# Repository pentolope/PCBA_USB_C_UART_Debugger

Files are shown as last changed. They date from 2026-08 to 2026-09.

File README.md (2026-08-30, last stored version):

# USB-C UART Debug Adapter

USB-C to 3.3 V UART debug adapter: bus-powered USB 2.0 Full-Speed device breaking out TX/RX/GND/3V3 and optional RTS/CTS.

This repository holds the design problem for a **USB-C to 3.3 V UART debug adapter**. The brief fixes the function and the interface contract: a bus-powered USB 2.0 Full-Speed device with a correct USB-C device-side CC network, USB ESD protection close to the connector, local decoupling, and a target-side header carrying TX, RX, GND, a 3V3 reference and optional RTS/CTS on a 0.1-inch or compact locking header. It also fixes process intent: pick a commonly available USB-UART bridge, prefer two layers, route D+/D- as a deliberate differential pair, and document whatever impedance approximation is used. The brief's own modality is carried across unchanged: RTS/CTS is offered as an option, two layers is a preference, and the benchmark-intent clauses say what the repository *should* do rather than what it must.

Everything else is the design agent's to decide. The brief names no bridge IC, no connector part, no ESD device, no board outline, no stackup numbers and no impedance target — those belong in `open_decisions`, not in this README. Where a choice is made during design it must be made and justified against cited evidence, not back-filled into the brief as if the user had asked for it.

> **This board has not been designed.** There is no schematic, no layout and no
> part selection here — only the brief, a reading of the brief, and the
> scaffolding a design run needs. That is the intended state of this repository,
> not a gap in it.

## What the brief fixes, and what it leaves open

The brief pins down 16 requirements and deliberately leaves
17 decisions to whoever designs the board. The `Source` column says
which is which: `brief` is quoted from [BRIEF.md](BRIEF.md), `metadata` comes
from the benchmark catalogue, and `open` means the brief does not fix it.

| Aspect | Value | Source |
|---|---|---|
| Product function | USB-C to 3.3 V UART debug adapter | brief |
| UART signalling level | 3.3 V | brief |
| USB interface class | USB 2.0 Full-Speed device | brief |
| Power source | Bus-powered (no separate supply input stated) | brief |
| Target-side signal set | TX, RX, GND, 3V3 reference, plus RTS/CTS as an option | brief |
| Target-side header style | 0.1-inch header or a compact locking header (the brief permits either; which one is not fixed) | brief |
| USB-C CC network | Correct device-side CC network required; no topology, value or tolerance stated | brief |
| ESD protection | USB ESD protection, placed close to the connector | brief |
| Decoupling | Local decoupling required | brief |
| Connector placement | USB and target-side connectors clearly separated | brief |
| USB-UART bridge | A commonly available bridge; no specific part named by the brief | brief |
| D+/D- routing | Deliberate differential pair; any impedance approximation must be documented | brief |
| Likely layer count | 2 (stated as a preference, not a mandate) | metadata |
| Primary stressors | USB 2.0 differential routing, ESD, USB-C CC resistors, small QFN | metadata |
| Board outline, size and mounting | Not fixed by the brief — design agent's choice | open |

The full split, with the verbatim brief text substantiating every fixed
requirement, is in [board/requirements.md](board/requirements.md) and
machine-readably in [board/requirements.json](board/requirements.json).

**Missing details are design freedom, not permission to fabricate unstated user
requirements.** A choice the brief left open is recorded as a decision, with its
reasoning — never promoted into a requirement.

## Benchmark position

| | |
|---|---|
| Benchmark id | 5 of 32 |
| Category | high-speed-lite |
| Difficulty | 2 / 5 |
| Brief detail | 3 / 5 |
| Likely layer count | 2 |
| Primary stressors | USB 2.0 differential routing, ESD, USB-C CC resistors, small QFN |

Board 05 sits in the `high-speed-lite` category at difficulty 2/5 with brief detail 3/5: an adapter of modest scope whose difficulty concentrates in doing four specific things correctly at once — USB 2.0 differential routing, ESD, the USB-C CC resistors, and a small QFN. The brief is deliberately mid-detail: it pins down the interface contract (speed class, power source, signal set, header style, protection placement) while naming no part, no dimension and no impedance number. The interesting test is the "Prefer two layers, but route D+/D- as a deliberate differential pair and document any impedance approximation" clause — it invites a controlled-impedance claim on a stackup that may not be able to guarantee one, and rewards an agent that documents the approximation honestly rather than asserting a number.

This repository is one of thirty-two. The suite, the protocol and the results
live in [PCBA_AutoDesignAndTest_Bench](https://github.com/pentolope/PCBA_AutoDesignAndTest_Bench).

## Repository layout

| Path | Contents |
|---|---|
| `BRIEF.md` | the supplied brief — authoritative, preserved byte for byte, never edited |
| `board/requirements.md` | what the brief fixes, what it leaves open, and where decisions get recorded |
| `board/requirements.json` | the same split, machine-readable, each fixed requirement bound to brief text |
| `board/manifest.template.json` | the toolkit's minimum manifest, pre-filled for this board |
| `board/toolchain.json` | where this board's build finds KiCad and the router |
| `benchmark/metadata.json` | the supplied catalogue entry — category, difficulty, detail, stressors |
| `docs/architecture.md` | the decisions this board must make, as questions, unanswered |
| `docs/sources.md` | the classes of evidence the design will have to cite |
| `docs/status.md` | what exists, what does not, and what is deliberately absent |
| `candidates/` | disposable search output, ignored by Git |
| `.claude/skills/` | the accountability-review skill [CLAUDE.md](CLAUDE.md) requires before a push |
| `tooling/PCBA_AutoDesignAndTest` | the shared verification/routing/release toolkit, as a pinned submodule |

## Getting the repository

The toolkit is a submodule and carries KiCad Routing Tools as a submodule of its
own, so clone recursively:

```bash
git clone --recursive https://github.com/pentolope/PCBA_USB_C_UART_Debugger.git
```

```bash
git submodule update --init --recursive
```

## Designing the board

Generic verification, routing and release logic is **not** written here. It is
consumed from `tooling/PCBA_AutoDesignAndTest`, which is board-agnostic by
construction and must stay that way; this repository owns the board and nothing
else. Start from
[the toolkit's onboarding guide](tooling/PCBA_AutoDesignAndTest/examples/onboarding.md),
and see [CLAUDE.md](CLAUDE.md) for the rules a design run works under.

```bash
python3 tooling/PCBA_AutoDesignAndTest/run.py preflight
```

## Brief integrity

`BRIEF.md` SHA-256 `0c5897542317b8fdc90d1251febe01efa33c86589f59024910c426d053b9a461`

Every quotation in `board/requirements.json` is bound to those exact bytes. If
the brief ever changes, the bindings are stale by construction — which is the
point of recording the digest.

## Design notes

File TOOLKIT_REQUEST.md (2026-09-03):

# Toolkit request from board 05 (USB-C UART debugger)

This is a request list from one board to the toolkit it is validated by. It
was written after taking this board from a brief to a release-ready commit,
and every item below is a wall this board actually hit, quoted where the
toolkit says in its own words what it will not do.

Two rules govern the list:

1. **Nothing here may make the toolkit board-specific.** Each request states
   the general form the facility should take. Where this board is mentioned
   it is as the reporter of a wall, never as the shape of the answer. A
   request that could only be satisfied by knowing about USB, Type-C, or any
   part on this board has been rewritten until it no longer is.
2. **Nothing here asks the toolkit to be less strict.** Every facility
   requested must fail closed, refuse rather than guess, carry its model and
   its validity window in the claim, and be reachable only by an explicit
   manifest declaration. Several of these requests exist *because* the
   toolkit correctly refused, and the fix is a new model, not a relaxed one.

Priority is the order in which these would change what a board can honestly
claim, highest first.

| # | Request | Doc | Blocks today |
|---|---|-----|---|
| 1 | Coupled-line model for differential pairs | §21.2 | An UNKNOWN impedance claim on any pair-carrying board |
| 2 | Reactive interconnect models for post-layout simulation | §21.1, §22 | Half of §22's own question list |
| 3 | Plane and multi-path DC, and PDN quantities | §23 | Any rail with decoupling; every poured net |
| 4 | Verification-method classification | §26 | Not expressible in the claim model |
| 5 | External and manual release dependencies | §25, §30 | Nowhere to record what is verified off-tool |
| 6 | Fabricator facts the catalog does not carry | §7, §25 | Two via gates permanently NOT_APPLICABLE |
| 7 | Component rotation as a toolkit facility | §25 | Per-board duplication; unreviewed CPL angles |
| 8 | Correlated uncertainty in matched groups | §21.1 | Undecidable skew on unavoidable geometry |
| 9 | A defined seam for full-wave extraction | §21.3 | No path from geometry to a solver |

---

## 1. A coupled-line model for differential pairs

### What stopped me

The toolkit refuses, correctly and in full:

```
REFUSED: differential solving is not implemented in this pass: the analytic
infrastructure carries no coupled-line model, and an uncoupled pair presented
as a differential answer would be wrong by construction
```

`pcbqa/transmission_line.py` implements bare microstrip, coated microstrip
and stripline, all single-ended. `run.py fab impedance` already accepts
`--mode differential`, so the interface exists and the model behind it does
not.

The consequence for this board is one claim that cannot be resolved:
`usb_pair_differential_impedance_matches_the_usb_nominal` reports UNKNOWN,
with the omission recorded as *"no coupled-line model is available"*. That is
the honest answer, and it is the only unresolved electrical question on an
otherwise fully evaluated board. Any board carrying a differential interface
will land in the same place.

Two supporting facts, both already inside the toolkit:

- `pcbqa/coupling_geometry.py` measures coupled run length and says of its
  own output: *"geometric proximity for risk ranking only; this is coupled
  run length in mm, not a crosstalk voltage, and no electrical conclusion
  follows until a sourced coupling model consumes it."* Nothing consumes it,
  and no gate reaches it, so a board cannot even obtain the inventory.
- `pcbqa/claim.py` already reserves the phenomena `characteristic_impedance`
  and `coupling` and the scope level `pair`. The vocabulary was designed for
  this; only the producer is missing.

### What I want

A coupled two-conductor model beside the existing single-ended ones, with the
same discipline: a stated form, a stated validity window on the normalised
geometry, and a refusal outside it rather than an extrapolation.

- odd- and even-mode impedance, and differential and common-mode impedance
  derived from them;
- edge-coupled microstrip (bare and mask-coated) and edge-coupled stripline,
  since those are the geometries a two-conductor pair on a fabricated board
  actually takes;
- the same effective-permittivity helpers the delay model uses, so impedance
  and delay can never disagree about the geometry — the single-ended code
  already makes that promise and the coupled code should inherit it;
- consumption of the existing coupled-run-length inventory, so the model is
  applied to the length the board really runs coupled and not to a declared
  ideal.

Second, a **fabricator-report path** for boards that can buy impedance
control. The frozen catalog already carries the fabricator's impedance model
inputs — prepreg and core Dk by thickness, soldermask Dk, the offered
differential range, and `Impedance Tolerance ±10%`. It also records that
controlled impedance is offered only at `4/6/8/10/12/14/16/18/20/.../32
layers`. That last fact is a first-class answer the toolkit should be able to
give: on a two-layer construction no fabricator impedance report can exist,
so a model is the only route to the claim, and a board should learn that from
the toolkit rather than deduce it.

### Interface

- `pcbqa.transmission_line.coupled_microstrip_zdiff(...)` and the stripline
  equivalent, returning odd/even mode plus effective permittivity, refusing
  outside the window.
- `run.py fab impedance --mode differential` stops refusing where the
  construction and geometry are inside the model's window; keeps refusing,
  with the reason, where they are not.
- A gate, opt-in like every other: `SI.PAIR_IMPEDANCE`, driven by a
  `differential` block under an existing `timing.interfaces.<name>` —
  conductor width, edge-to-edge gap, reference layers, target impedance and
  tolerance. It measures the realised geometry off the board, not the
  declared geometry, exactly as the delay gate does.

### How it must refuse

- Outside the validity window of the form: refuse, naming the geometry ratio
  and the window.
- Where the two conductors are not uniformly coupled over the measured run
  (fan-out, launch, via transitions): report the uncoupled portion as an
  explicit omission, in the same shape the delay gate uses for unreferenced
  length, and let the board declare a budget for it.
- Where the reference structure under the pair is interrupted beyond that
  budget: refuse, because an impedance stated over a broken reference
  describes a structure the board does not have.

### Done when

A board can declare a differential interface and receive PASS, FAIL or a
stated refusal — never silence — and the claim carries the model name, the
validity window, and the coupled length it was evaluated over.

---

## 2. Reactive interconnect models for post-layout simulation

### What stopped me

The extracted interconnect model is a resistor. Literally:

```python
"spice": ".subckt {identity} a b\nR1 a b {value}\n.ends"
```

and the geometry baseline says of itself: *"geometry-derived quantities only;
no inductance or capacitance is claimed anywhere in this report."*

§22 lists the questions post-layout simulation exists to answer. With an
R-only model, these are unanswerable on any board: *did via inductance create
ringing?*, *did the decoupling-loop geometry degrade transient behaviour?*,
*did a switching loop become too inductive?*, *did the routed impedance
invalidate the nominal termination?* The rail-drop questions are answerable
and the reactive ones are not, which quietly limits post-layout simulation to
DC.

### What I want

Per-unit-length capacitance and inductance from the same geometry and
stackup the propagation model already uses, and via barrel inductance beside
the via *delay* model that already exists, emitted as a richer subcircuit
under the same alias mechanism that makes extracted models usable from a
stored scenario.

- a distributed or lumped-segment RLC subckt, segment count chosen from the
  path's own electrical length so the model is not finer or coarser than the
  question deserves;
- the R-only model kept and still selectable, because for a pure DC drop it
  is the honest minimum and costs nothing;
- the choice declared by the board, not inferred: a scenario asks for the
  model it wants and the toolkit refuses if it cannot build it.

### How it must refuse

The reactive model must inherit the delay model's reference discipline: if a
portion of the path runs with its reference interrupted beyond the board's
declared budget, refuse rather than emit an inductance computed from a loop
that is not there. This is the same rule that already governs delay, and it
is the reason the delay numbers on this board can be trusted.

### Done when

A board can substitute a routed path into a pre-layout scenario and see a
transient that differs from the ideal one for reasons the model can name.

---

## 3. Plane and multi-path DC, and the power-integrity quantities

### What stopped me

`extract.path_resistance` refuses two situations that are not exceptional —
they are what supply distribution normally looks like:

```
net 'GND' carries filled zone copper; plane current paths are not modelled by
path-scoped DC extraction
```

```
traversal element 32 on net '+3V3' begins and ends in one electrical node;
its series resistance would be fictitious, and the path-scoped model refuses
```

Both refusals are right. Their combined effect on this board is that the
regulator output rail — the one with the decoupling on it — cannot be
measured at all, and neither can any return path, because the return is a
pour. What can be measured is only what happens to be a bridge in the graph.
On this board that left the receptacle-to-regulator run (36.3 mΩ over
21.4 mm, two vias), the switched supply to the target header (24.5 mΩ), and
the series-terminated signal runs. The decoupled rail and the ground return
are invisible.

§23 asks for source-to-load DC resistance, distribution voltage drop,
via/current bottlenecks, plane spreading resistance, decoupling-loop
inductance, plane inductance, local supply impedance, PDN impedance versus
frequency, anti-resonances and transient droop. Today a board can obtain the
first of those only when the copper happens to be a single series chain.

### What I want

1. **A network DC solve.** Where parallel copper exists, return the network
   resistance between the named terminals instead of refusing. Parallel
   copper divides current, which is a solvable fact, not an ambiguity. Keep
   the refusal for the case it was written for — a *series* model asserted
   over a parallel network — by making the network solve a different,
   explicitly requested answer with its own claim shape.
2. **Poured nets included.** A nodal solve over the filled zone polygons,
   with the vias as the connections between layers, giving source-to-load
   resistance including plane spreading. This is the only route to a return
   path number on any board that uses a plane, which is nearly all of them.
3. **Decoupling-loop inductance from geometry.** The claim vocabulary already
   reserves `loop_inductance` and nothing produces it. The loop is
   measurable: pad, via, plane, via, pad, all present in the board file.
4. **Current bottlenecks.** Given a rail and a current, report the narrowest
   cross-section and the via count carrying it, which is a geometry question
   the toolkit can already answer and nobody can currently ask.

### Interface

A `power` block in the manifest, opt-in, listing rails: a source terminal,
load terminals, the current each draws, and the drop each tolerates. Gates
`PDN.DC_DROP` and `PDN.RETURN_PATH`, reporting measured drop against the
declared limit, and the return path's resistance against its own.

### How it must refuse

State the solver, the mesh resolution and the convergence criterion in the
claim. Refuse when the pour is unfilled, when a zone's fill is stale with
respect to the copper, or when a declared terminal is not on the net.

---

## 4. Verification-method classification

### What stopped me

§26 asks that every significant requirement identify the strongest
verification method currently available, from a stated vocabulary. No claim
in this board — or in any board in this bench — carries one. The nearest
thing is `evidence_class`, which is free text and describes the evidence
rather than the method that established it.

The gap matters most where a requirement is *satisfied by argument*. This
board's ESD claims establish that every entering conductor is clamped, which
is a structural fact, not a compliance result. Nothing in the artifact says
that the compliance claim itself requires physical test. §26 explicitly wants
that distinction, and there is nowhere to write it.

### What I want

A closed vocabulary as a first-class claim field — `STATIC`, `GEOMETRY`,
`ANALYTIC`, `CIRCUIT_SIM`, `DIGITAL_SIM`, `EXTRACTED`, `EM_SIM`,
`THERMAL_SIM`, `MANUFACTURING_CHECK`, `PHYSICAL_TEST`, `DOCUMENTATION` — with
a claim able to name more than one, and able to name a method it does *not*
have as the one that would be required to close it.

A gate, `PROV.VERIFICATION_METHOD`, that checks every requirement-bearing
claim names a method, and lets a board declare a minimum method per
significance class, so a board can say that its safety-relevant requirements
may not rest on `DOCUMENTATION` alone.

### How it stays board-agnostic

The vocabulary is fixed by the toolkit; which method a claim carries is the
producer's statement; which minimum a board demands is the board's policy.
Nothing about any particular requirement is encoded in the toolkit.

---

## 5. External and manual release dependencies

### What stopped me

§25 says of steps that cannot be validated locally that they *"should be
recorded as external/manual release dependencies rather than silently
assumed"*, and §26 says the agent should be rewarded for correctly saying
physical validation is still required.

There is nowhere to record either. `release-check` prints RELEASE READY or a
list of failures; a board with an open dependency on a fabricator's assembly
preview, a physical ESD test, or a bench measurement of a quantity no model
can establish has no way to carry that in the artifact. The absence reads as
"nothing is outstanding", which is exactly the silent assumption the document
warns against.

### What I want

An `external_dependencies` block in the manifest, and a gate over it. Each
entry: an id, the statement it would establish, the verification method from
§26's vocabulary, who owns it, its status, the evidence that closes it, and
whether it blocks release. The gate checks the shape and the evidence;
`release-check` prints open dependencies as part of its verdict and refuses
release-ready while a blocking one is open.

Alongside it, §30's policy states — `analysis-only`,
`provisional-layout-allowed`, `fabrication-ready`, `release-ready`,
`requires-human-review`, `blocked` — as an explicit output of validation
rather than something a reader infers from a gate table. A positive result at
one stage should not read as authorisation for the next, and today it does.

---

## 6. Fabricator facts the catalog does not carry

### What stopped me

`fab/selection.json` states its own limits precisely: *"feasible means
feasible against the checked requirements only; the properties under
not_in_vocabulary were NOT inspected and must be judged separately"*, and the
uninspected list includes solder-mask constraints, via covering (tented /
plugged / filled), annular ring, edge-to-copper clearance and assembly
constraints.

The frozen catalog carries soldermask *thickness* — base, on copper, between
traces — but no mask expansion, registration or minimum dam. So
`via_mask.process.limit_mm` cannot be sourced from evidence, and
`VIA.MASK_CLEARANCE_PROCESS` and `VIA.NATIVE_GERBER_AGREEMENT` are
NOT_APPLICABLE on every board in this bench. The gates exist and nothing can
legitimately turn them on.

### What I want

Extend the catalog vocabulary to the properties in that list, under the same
committed-evidence policy the rest of it follows: source, retrieval date,
excerpt, digest. Then expose them, so a board writes

    "via_mask": {"process": {"limit_mm": {"from_catalog": "soldermask_min_dam_mm"}}}

instead of inventing a number or leaving the gate dark. The same applies to
via covering: a board should be able to declare tented, plugged or open and
have the declaration checked against what the fabricator offers, because that
choice changes what the via gates mean.

---

## 7. Component rotation as a toolkit facility

### What stopped me

Rotation correctness is a per-part fact about a fabricator's library, not
about a board, and it is currently implemented per board: an earlier board in
this bench carries its own `tools/jlc_orientation.py` plus per-part frozen
library responses, and derives each offset by pairing library pads against
footprint pads. This board has neither, so its CPL ships KiCad's angles with
nothing behind them — and a wrong rotation on a fine-pitch package is a
scrapped build, not a warning.

Copying a tool between boards is exactly the duplication a board-agnostic
toolkit should absorb. The gate for it, `CPL.ORIENTATION`, is already in the
toolkit; only the means of producing evidence for it is not.

### What I want

A `fab orientation` subcommand: fetch a part's library geometry under the
same network policy that governs `fab refresh` — that is, never during
validation — derive the offset by pad pairing, require every pad to agree,
score the runner-up, and write per-part evidence with a digest. A board then
declares the registry and reviews it; the gate re-derives from the committed
evidence and compares.

The pad-pairing derivation is general: it needs a footprint and a library
geometry, and knows nothing about the part.

---

## 8. Correlated uncertainty in matched groups

### What stopped me

The skew gate treats each member's length uncertainty as independent. Before
I redrew this board's pair, all four of its paths carried exactly 0.9625 mm
of junction ambiguity — identical, because the endpoints are identical — and
the group spread came out as the interval 0 to 1.925 mm against a 0.2 mm
limit. Not a failure: undecidable, by construction, for any matched pair
whose members share their endpoint geometry.

I closed it in the board by ensuring nothing lands part-way along a
conductor, which removed the ambiguity rather than cancelling it. That fix is
not always available: a board whose group members must pass through a pad or
a via mid-run has no route to a decidable skew number, however well matched
the copper is.

### What I want

Either a way for a group to declare that its members' endpoint ambiguity is
shared — checked, not asserted, by comparing the junction identities the
extraction already computes — or a spread calculation that cancels the
ambiguity it can prove is common and reports only the residual. The gate
should still report the ambiguity it cancelled, so the reader can see what
was assumed.

---

## 9. A defined seam for full-wave extraction

§21.3 is right that the hard part is not calling a solver: it is geometry
translation, meshing, ports, references, boundaries and de-embedding. I am
not asking the toolkit to own a solver. I am asking for the seam to be
defined now, so the boundary is a decision rather than an accident.

A documented region export — an electrical path, the copper around it within
a stated distance, the stackup, and port definitions at named terminals —
written in a form a solver can consume and a claim can cite. Whatever
consumes it must refuse release-grade claims when port definition, reference
definition or de-embedding cannot be established, which is what the document
already asks for.

The candidates on a board like this one are the connector launch and the via
transitions — precisely the places the analytic model already declares
outside its validity.

---

## What I am not asking for

- Anything that names a bus, a connector family, a part or a vendor part
  number in toolkit code.
- Any relaxation of a refusal. Where the toolkit refuses today it is right to
  refuse; the request is a model that makes the refusal unnecessary, not a
  switch that suppresses it.
- Any gate that passes by default. Everything above is opt-in by manifest
  declaration and NOT_APPLICABLE until a board declares it, like every gate
  that exists now.
- Any facility that reads the network during validation.

## What this board would do with each

1. Close its differential-impedance claim, or receive a stated refusal that
   names the geometry rather than the missing model.
2. Rerun its hot-plug and edge scenarios over routed copper with reactive
   parasitics, not just resistance.
3. Measure the drop to its regulator across the decoupled rail, and the
   return path through the pour, neither of which it can measure now.
4. Mark its ESD coverage as an argument requiring physical test, in the
   artifact rather than in prose.
5. Record the assembly-preview and physical-test dependencies it currently
   cannot state at all.
6. Turn on the two via gates that are dark for want of a sourced number.
7. Ship a CPL whose angles have been derived and reviewed rather than
   inherited.
8. Keep its skew claim decidable if the pair ever has to pass through
   something mid-run.
9. Point a solver at its receptacle launch when the analytic answer is not
   enough.

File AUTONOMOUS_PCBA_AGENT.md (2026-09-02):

# Autonomous PCBA Agent — Architecture and Development Plan

**Status:** Working architecture / roadmap  
**Scope:** Board-agnostic autonomous PCBA development using KiCad and the `PCBA_AutoDesignAndTest` toolkit  
**Manufacturing target:** JLCPCB unless the toolkit's scope is deliberately changed in the future  
**Primary goal:** Enable an AI agent to turn a product brief into a defensible, manufacturable PCBA with minimal human interaction, while keeping every machine-readable claim inside the evidence actually established.

---

# 1. Mission

The system is intended to develop real PCBAs, not merely produce plausible schematics or visually convincing layouts.

The long-term autonomous flow is:

```text
product brief
    ↓
requirements + assumptions
    ↓
architecture + component selection
    ↓
schematic
    ↓
static schematic verification
    ↓
pre-layout electrical / functional simulation
    ↓
fabrication process + stackup
    ↓
placement + routing constraints
    ↓
placement
    ↓
routing
    ↓
physical validation
    ↓
parasitic extraction
    ↓
post-layout electrical / functional simulation
    ↓
targeted SI / PI / EM / thermal analysis where required
    ↓
design iteration
    ↓
fabrication + assembly outputs
    ↓
release gates
```

The objective is not an AI that merely "draws a PCB." The objective is an autonomous electrical-design system that can:

- interpret an incomplete human brief;
- derive reasonable engineering requirements;
- make and record assumptions;
- select defensible components and architectures;
- build and verify a schematic;
- simulate what can be simulated before spending effort on PCB layout;
- express physical intent as machine-readable constraints;
- use search/optimization for placement and routing;
- extract geometry-dependent electrical behavior;
- repeat simulations with the physical interconnect included;
- diagnose failures in terms of design variables;
- revise the design until the available evidence supports the required claims;
- generate reproducible fabrication and assembly outputs;
- refuse claims that the available evidence does not support.

The system should optimize for **conservative autonomy**: proceed autonomously when a decision is reversible and sufficiently supported, but never convert missing evidence into an implicit PASS.

---

# 2. Implementation context and architectural boundaries

This document describes both current foundations and future target capabilities.

The existing `PCBA_AutoDesignAndTest` toolkit already provides important pieces of the architecture, including:

- KiCad-centered validation;
- fail-closed result handling;
- board-owned declarative policy;
- fabrication and release evidence;
- routing provenance and candidate isolation;
- electrical-path analysis;
- parasitic-related analysis;
- component delay/model concepts;
- simulation scenario, fidelity, digital, and ngspice infrastructure;
- JLCPCB process evidence;
- reproducible release checks.

Not every capability described in this roadmap exists yet.

A future backend or solver must not be represented as implemented merely because the architecture anticipates it. Production code should expose a capability only when there is a real implementation and a defined result contract.

The architecture therefore distinguishes:

```text
implemented capability
planned capability
unsupported capability
```

An unsupported capability is not a degraded PASS.

---

# 3. Roles and authority

The system should divide responsibilities deliberately.

## 3.1 AI agent

The AI is the electrical engineer and iteration controller.

It is responsible for:

- interpreting the product brief;
- deriving requirements;
- recording assumptions;
- selecting architectures;
- selecting components;
- locating and interpreting source evidence;
- choosing which simulations and analyses are necessary;
- defining electrical intent;
- defining placement and routing constraints;
- interpreting failures;
- deciding which design variables to modify;
- deciding when additional analysis is warranted;
- explaining unresolved uncertainty.

The AI should normally specify **intent and constraints**, not manually choose every trace vertex or component coordinate.

---

## 3.2 KiCad project

Native KiCad files are authoritative for the realized electrical and physical design.

They are the authority for things such as:

- schematic connectivity;
- assigned symbols and footprints;
- PCB geometry;
- copper;
- pads;
- vias;
- zones;
- board outline;
- stackup representation;
- net classes;
- design rules.

A generator may be the source of the intended design, as in a generated-board workflow, but the generated KiCad design still must be independently checked for parity with that source.

Nothing is considered physically true merely because a planning document or Python object says it is true.

---

## 3.3 PCBA_AutoDesignAndTest toolkit

The toolkit is the machine-facing authority for:

- validation;
- evidence provenance;
- constraint interpretation;
- model coverage and fidelity;
- physical measurements derived from authoritative design data;
- routing provenance;
- simulation result contracts;
- fail-closed behavior;
- manufacturing validation;
- fabrication artifact binding;
- release gates.

The toolkit should measure and judge declared policy. It should not silently invent board-specific policy.

Board-specific requirements belong in the board repository.

---

## 3.4 Optimization and geometry engines

Numerical/search engines should handle problems where explicit coordinate generation by a language model is weak or unnecessarily brittle.

Examples:

- component placement;
- placement legalization;
- ordinary routing;
- differential routing;
- length or time tuning;
- routing candidate generation;
- candidate ranking;
- geometric optimization.

The AI defines what a good solution means. Search engines explore the geometric solution space.

---

## 3.5 Simulation and extraction backends

Simulation backends establish modeled electrical or functional behavior.

Extraction backends establish physical quantities from PCB geometry.

They must report:

- what was analyzed;
- with what model;
- at what fidelity;
- under what conditions;
- with what omissions;
- with what provenance;
- whether the result is exact, bounded, approximate, unknown, or unsupported where applicable.

A simulator completing successfully does not by itself establish that its models were adequate for the claim being made.

---

## 3.6 Git

Git is the authority for design history and release identity.

Use Git for:

- immutable history;
- branches;
- comparison;
- rollback;
- submodule pins;
- release tags.

Do not invent a parallel revision-control state machine.

A substantial design alternative should be an isolated branch or reproducible candidate, not an undocumented mutation of the accepted board.

---

# 4. Engineering statement types

The autonomous agent should preserve the origin and status of important engineering statements.

At minimum, distinguish:

## 4.1 User requirement

A requirement explicitly stated by the product brief or human stakeholder.

Example:

```yaml
kind: user_requirement
statement: board shall operate from a 5 V host supply
source: product_brief
```

---

## 4.2 Derived engineering requirement

A requirement the agent derives because it is necessary to satisfy a user requirement, safety condition, interface contract, manufacturing constraint, or established engineering limit.

Example:

```yaml
kind: derived_requirement
statement: USB data traces require controlled differential routing
derived_from:
  - USB 2.0 interface requirement
rationale: interface electrical requirements
```

Derived requirements should state their rationale and evidence.

---

## 4.3 Assumption

A fact the brief did not establish but the design currently depends on.

Example:

```yaml
kind: assumption
statement: relay contacts will switch 24 VDC loads
reason: load voltage was not specified
revisable: true
```

Assumptions must remain visible because later evidence may invalidate them.

---

## 4.4 Design decision

A choice among multiple valid implementations.

Example:

```yaml
kind: design_decision
statement: use a star-point current-sense return
alternatives_considered:
  - shared return plane
  - dedicated sense return
rationale: reduce load-current error coupling
```

A design decision must not be presented as though it were a user requirement.

---

## 4.5 Verification requirement

A statement that defines what evidence is needed to establish another requirement.

Example:

```yaml
kind: verification_requirement
requirement: output rail transient droop
method:
  - pre_layout_spice
  - post_layout_spice_with_extracted_pdn
```

This separation makes failures diagnosable. A board can fail because the AI derived the wrong requirement, made a bad assumption, implemented a valid requirement incorrectly, or failed to verify it adequately.

---

# 5. Evidence and claim discipline

The architecture should converge on one conservative evidence vocabulary rather than creating independent notions of "quality" in every subsystem.

A produced quantity should carry, where relevant:

- phenomenon;
- scope;
- value and units;
- knowledge form:
  - exact value;
  - lower bound;
  - upper bound;
  - interval;
  - approximate;
  - unknown;
- evidence class;
- source/provenance;
- applicability;
- operating conditions;
- assumptions;
- omissions;
- requirement being evaluated;
- verdict.

Core rules:

1. **Unknown is not PASS.**
2. **An omitted contribution is not zero.**
3. **A reason for omitting a contribution is not a measurement.**
4. **A lower bound can prove that a maximum is exceeded, but cannot prove that the maximum is met.**
5. **A model that does not cover the required phenomenon cannot be upgraded by another strong model elsewhere in the simulation.**
6. **Simulator convergence is not model adequacy.**
7. **A nominal-design result is not automatically a fabrication or release result.**
8. **A report must not claim more than its dependency closure supports.**

Where the toolkit already has an evidence/claim representation, new producers should migrate into it rather than defining another parallel verdict system.

---

# 6. Repository architecture

## 6.1 PCBA repository

A board repository should own the physical hardware contract and board-level verification intent.

A representative target layout is:

```text
PCBA/
├── schematic/
├── pcb/
├── constraints/
│   ├── requirements.*
│   ├── assumptions.*
│   ├── electrical_paths.*
│   ├── placement.*
│   └── routing.*
├── components/
│   ├── selection.*
│   ├── pin_mappings.*
│   ├── models.*
│   └── provenance.*
├── interfaces/
│   ├── signals.*
│   ├── pins.*
│   ├── clocks.*
│   ├── protocols.*
│   └── electrical_limits.*
├── simulation/
│   ├── scenarios/
│   ├── spice/
│   ├── digital/
│   └── fixtures/
├── extracted/
│   ├── parasitics/
│   ├── sparameters/
│   └── power/
├── fabrication/
├── assembly/
├── generated/
├── docs/
└── tooling/
    └── PCBA_AutoDesignAndTest/
```

This is an architectural organization, not a requirement to rename an existing consumer repository.

The board repository should own:

- product and derived requirements;
- assumptions;
- architecture decisions;
- selected components;
- source provenance;
- schematic and PCB;
- physical/mechanical constraints;
- JLCPCB process and selected stackup;
- pin and electrical interface contracts;
- placement/routing intent;
- timing, impedance, power, safety, thermal, and signal-integrity requirements;
- board-level behavioral models;
- simulation scenarios;
- extracted PCB parasitics and S-parameters;
- model assumptions and fidelity;
- fabrication/assembly decisions;
- release evidence.

---

## 6.2 Generated-board workflows

The architecture must support boards whose schematic and PCB are generated.

A generated design may use a board-owned design source such as:

```text
netlist + component declarations + placement intent
        ↓
schematic generator
        ↓
KiCad schematic
        ↓
PCB generator
        ↓
KiCad PCB
```

This is acceptable only if the generated result is checked.

Useful independent parity gates include:

- design-source netlist ↔ KiCad schematic;
- KiCad schematic ↔ KiCad PCB;
- intended placement constraints ↔ realized PCB placement;
- declared critical-route topology ↔ realized copper.

The generator does not exempt the generated board from ERC, DRC, model mapping, or physical verification.

---

## 6.3 Firmware / software repository

The firmware/software repository should own implementation software.

```text
firmware/
├── hardware/
│   └── pcba/      # submodule pinned to a PCBA revision
├── fpga/
│   ├── rtl/
│   └── tests/
├── mcu/
├── host/
└── integration/
```

The firmware repository may consume machine-readable PCBA artifacts such as:

- pin assignments;
- clocks;
- voltage domains;
- FPGA constraints;
- protocol definitions;
- generated headers;
- board-level behavioral interfaces;
- simulation fixtures.

Do not maintain two independently edited copies of the same board contract.

---

## 6.4 Optional product-integration repository

For larger systems:

```text
product/
├── hardware/
├── firmware/
└── integration/
```

This repository may pin a known-good combination of:

```text
PCBA revision
+ FPGA revision
+ MCU firmware revision
+ host software revision
```

---

# 7. Controlled source acquisition

Autonomous design often requires external evidence:

- datasheets;
- application notes;
- SPICE models;
- IBIS models;
- package drawings;
- reference designs;
- manufacturer process rules;
- assembly capabilities;
- part availability.

The design agent may acquire such evidence during design exploration.

However, **live network state must not determine a release verdict**.

Before an external fact is allowed to support a release-grade claim, it should be frozen or referenced in a reproducible way with appropriate provenance, such as:

- source;
- document identity;
- revision/date;
- retrieval date where relevant;
- applicable device/process;
- units;
- conditions and exceptions;
- content digest where practical.

JLCPCB process data used by the toolkit should follow the toolkit's committed-evidence policy. Manufacturer-independent physics should remain separate from manufacturer-specific capability data.

---

# 8. Component selection is a first-class design stage

Component selection is not a clerical step between architecture and schematic capture.

The agent should evaluate candidate parts against:

- electrical requirements;
- absolute maximum ratings;
- operating conditions;
- package suitability;
- thermal capability;
- supply chain and lifecycle information where available;
- JLCPCB assembly availability when relevant;
- manufacturability;
- footprint confidence;
- documentation quality;
- model availability;
- simulation fidelity;
- interface compatibility;
- cost where the product brief makes cost relevant.

Model availability is an engineering advantage, but absence of a detailed model does not automatically make a part invalid.

The important rule is honesty:

> If a design depends on behavior that cannot be established for the selected component, the resulting claim remains unsupported or provisional.

The agent may prefer a part with a strong vendor model over an otherwise equivalent part with no usable model when that materially improves design confidence.

---

# 9. Symbol, footprint, package, and model correspondence

A critical autonomous-design gate is the mapping:

```text
datasheet package pin
        ↕
schematic symbol pin
        ↕
PCB footprint pad
        ↕
physical package terminal
        ↕
SPICE / IBIS / behavioral model terminal
```

These correspondences must be established independently.

A simulation cannot validate the manufactured implementation if the simulated terminal mapping and physical package mapping can both be wrong in the same way.

The system should record, where applicable:

- manufacturer part number;
- package designation;
- package drawing source;
- symbol source;
- footprint source;
- pad numbering;
- exposed-pad handling;
- no-connect pins;
- power-pad requirements;
- model node order;
- model-to-symbol mapping;
- confidence/provenance.

Hard release blockers should include unresolved contradictions such as:

- footprint pad numbers disagree with package drawing;
- model terminal order is unknown;
- schematic symbol pin type or numbering is incompatible with the selected part;
- selected package variant does not match the footprint;
- required exposed pad is omitted or assigned incorrectly.

---

# 10. Single machine-readable hardware contract

Long term, duplicate declarations across PCB, simulation, firmware, and verification should be minimized.

Example:

```yaml
signals:
  HOST_CLK:
    direction: device_input
    voltage_domain: 3V3
    max_frequency_hz: 25000000
    timing_group: host_bus

  SENSOR_CLK:
    direction: device_output
    nominal_frequency_hz: 3072000
    electrical_path_group: sensor_clock_tree
```

The hardware contract should eventually generate or validate:

- EDA constraints;
- firmware constants;
- FPGA constraints;
- testbench interfaces;
- SPICE stimuli;
- timing constraints;
- ElectricalPath declarations;
- board validation rules;
- simulation scenarios.

The architecture should avoid requiring the agent to keep multiple independent descriptions synchronized by prose.

---

# 11. Design-stage gates

The autonomous workflow should use explicit stages rather than one final "board passes" decision.

A stage may have outcomes such as:

```text
PASS
PROVISIONAL
NOT_APPLICABLE
UNSUPPORTED
BLOCKED
ERROR
```

Exact names should follow the toolkit's implemented result vocabulary; the architectural point is that uncertainty must remain distinct from success.

---

## 11.1 Stage A — brief interpretation

Inputs:

- product brief;
- mechanical attachments;
- interface requirements;
- explicit constraints.

Outputs:

- user requirements;
- derived requirements;
- open questions;
- assumptions;
- verification plan;
- candidate architectures.

The agent should not receive hidden information such as benchmark difficulty or intended failure mode.

---

## 11.2 Stage B — architecture and component selection

Outputs:

- functional block diagram;
- power architecture;
- interface architecture;
- major components;
- risk register;
- component-model inventory;
- preliminary electrical budgets.

The agent should identify high-risk requirements early.

Examples:

- µV-level analog accuracy;
- high-current switching loops;
- controlled-impedance serial links;
- DDR timing;
- RF matching;
- isolation;
- thermals.

---

## 11.3 Stage C — schematic generation and static verification

Before PCB placement, the schematic should undergo static verification.

At minimum, where applicable:

- KiCad ERC;
- required pin connectivity;
- intentional no-connect audit;
- power-domain compatibility;
- regulator input/output limits;
- device absolute maximum checks;
- passive voltage/current/power ratings;
- connector pinout verification;
- interface voltage compatibility;
- reset/strap configuration;
- pull-up/pull-down sanity;
- output-contention checks;
- power-sequencing constraints;
- symbol/package/model mapping checks;
- netlist parity for generated designs.

A schematic with known blocking electrical errors should not proceed into detailed PCB layout merely because it can be routed.

---

# 12. Pre-layout electrical and functional simulation

**Pre-layout simulation is an explicit design gate.**

Before detailed PCB placement and routing, the agent should execute every meaningful electrical or functional scenario that can be evaluated from the schematic and the available models.

The purpose is to catch circuit-level failures before investing substantial effort in physical design.

---

## 12.1 What pre-layout simulation should test

Depending on the board:

### Power

- DC operating point;
- nominal rail voltages/currents;
- input-voltage corners;
- startup;
- shutdown;
- sequencing;
- load steps;
- transient droop;
- regulator stability where the available model supports it;
- current limiting;
- modeled fault cases.

### Analog

- bias points;
- gain;
- bandwidth;
- filtering;
- common-mode range;
- headroom;
- stability;
- noise where model fidelity supports it;
- input/output loading;
- sensor-conditioning behavior.

### Switching power and motor drive

- switch-node behavior;
- duty-cycle range;
- gate drive;
- dead time;
- inductor current;
- current-limit behavior;
- startup;
- load transients;
- control-loop behavior where models permit.

### Digital / mixed-signal boundaries

- reset sequencing;
- logic thresholds;
- voltage-domain compatibility;
- representative transactions;
- clock generation;
- basic timing relationships;
- contention;
- startup state.

---

## 12.2 Interconnect before layout

Pre-layout simulation does not yet have authoritative routed geometry.

Interconnect may therefore be represented as:

- ideal wires;
- explicitly estimated lumped R/L/C;
- nominal transmission lines;
- bounded analytic estimates;
- declared placeholder interconnect models.

The scenario must state which representation was used.

An ideal-wire pre-layout PASS does not establish post-layout signal integrity.

---

## 12.3 Pre-layout simulation policy

Do **not** require an impossible transistor-level whole-board model.

The correct rule is:

> Run all meaningful pre-layout simulations supported by available evidence, and explicitly report what could not be established.

A missing model can produce:

```text
unsupported
unknown
provisional
```

depending on the claim and policy.

It should not silently produce PASS.

Whether PCB work may proceed despite an unevaluated scenario is a policy question.

A reversible design may proceed provisionally when the missing evidence does not invalidate the architecture. A claim required for fabrication or release may remain blocking until adequate evidence exists.

---

## 12.4 Pre-layout iteration

A pre-layout failure should return to the responsible design variables:

```text
failure
  ├── component selection
  ├── topology
  ├── passive value
  ├── bias point
  ├── protection network
  ├── termination
  ├── power architecture
  └── model/assumption
```

The agent should correct the schematic-level problem before detailed PCB design.

---

# 13. Model registry and fidelity

Every simulated component or extracted quantity should identify its source and validity.

Possible model/evidence classes include:

```text
vendor-spice
vendor-ibis
rtl
datasheet-behavioral
assumed-behavioral
measured-behavioral
analytic-interconnect
quasi-static-extracted
full-wave-extracted
measured
unsupported
```

Do not treat these as a universal scalar quality ladder. Fidelity is phenomenon-dependent.

A model record should include, where relevant:

- identity/version;
- source/provenance;
- applicable component/package;
- terminal mapping;
- modeled phenomena;
- validity domain;
- reference temperature;
- voltage/current range;
- frequency range;
- consumed parameters;
- omissions;
- uncertainty or bounds if established;
- whether it may support nominal design;
- whether it may support a particular release claim.

---

## 13.1 Contributor-scoped model coverage

A mixed-fidelity simulation must not let one high-quality model "bless" a weak or missing contributor.

For each asserted measurement, the system should determine the dependency/contribution closure and report the coverage of each relevant model.

Example:

```text
measurement: 3V3 transient minimum
contributors:
    regulator vendor model        supported
    output capacitor ESR/ESL      bounded analytic
    load model                    datasheet behavioral
    PCB supply path               ideal in pre-layout run
```

This makes clear what the result actually establishes.

---

# 14. Primary SPICE backend

Use **ngspice** as the preferred automated SPICE backend.

Reasons:

- open;
- scriptable;
- suitable for CI;
- compatible with deterministic generated decks;
- practical for batch simulation;
- suitable for mixed-fidelity board scenarios.

LTspice or another simulator may be useful for:

- vendor-model compatibility;
- independent comparison;
- debugging a model that ngspice cannot evaluate.

No single simulator should define "whole-board verification."

---

# 15. Digital simulation

## 15.1 FPGA

When production RTL exists, use Verilator or another deterministic RTL backend where practical.

The PCBA repository may initially contain a simpler behavioral contract that captures only what the board requires.

```text
board simulation scenario
        │
        ├── board-owned behavioral model
        │
        └── production RTL
                │
                ▼
          digital simulator
```

Desired invariant:

> Production RTL must satisfy the board-level behavioral contract assumed by the electrical design.

---

## 15.2 MCU / SoC

Do not attempt transistor-level MCU simulation.

For PCBA verification, model the boundary behavior that affects the board:

- pin switching;
- voltage levels;
- source impedance;
- edge rate;
- timing;
- thresholds;
- pin capacitance;
- reset/startup sequence;
- protocol behavior;
- approximate load/current behavior when justified.

Possible levels:

1. board-owned behavioral stimulus;
2. emulator/virtual platform;
3. production firmware connected to a simulation harness;
4. hardware-in-the-loop after prototypes exist.

---

## 15.3 Simple digital logic

Use, in preference order where applicable:

- vendor electrical model;
- IBIS;
- SPICE/XSPICE;
- datasheet-derived behavioral model;
- explicit unsupported state.

A functional digital model must not silently imply accurate analog pin behavior.

---

# 16. ElectricalPath as a first-class concept

Routers operate on nets.

Electrical requirements often operate on a complete source-to-receiver path:

```text
driver package
    ↓
copper
    ↓
series resistor
    ↓
copper
    ↓
via transition
    ↓
receiver package
```

The toolkit therefore needs a first-class **ElectricalPath** representation independent of net boundaries.

ElectricalPath may carry requirements such as:

- maximum propagation delay;
- skew relative to another path;
- impedance;
- insertion loss;
- component traversal delay;
- allowed layer transitions;
- via count;
- topology;
- source/receiver identities.

Component traversals must not be assigned zero delay merely because their delay is unknown.

---

# 17. Fabrication process and stackup selection

The current manufacturing scope is JLCPCB.

The board should deliberately select a fabrication process and stackup before physical constraints that depend on them are frozen.

Selection may consider:

- layer count;
- finished thickness;
- copper weights;
- dielectric construction;
- controlled-impedance capability;
- via process;
- minimum track/space;
- minimum holes;
- solder-mask constraints;
- surface finish;
- assembly capability;
- cost;
- availability of required process options.

The selected stackup becomes an input to:

- impedance calculations;
- propagation estimates;
- via models;
- power resistance;
- plane geometry;
- future field solving.

Manufacturer process limits and conservative board design targets must remain distinct.

---

# 18. Placement strategy

## 18.1 Constraint-driven placement

The AI should normally generate:

- fixed anchors;
- functional blocks;
- grouping;
- relative relationships;
- orientation preferences;
- signal-flow order;
- power-flow order;
- keepouts;
- thermal restrictions;
- high-current-loop relationships;
- sensitive/noisy separation;
- mechanical restrictions.

A numerical optimizer should search the remaining freedom.

---

## 18.2 Semantic placement constraints

Examples:

- connector must lie on a specified edge;
- ESD protection must sit between connector and protected circuitry;
- decoupling must be electrically and geometrically close to target power pins;
- series termination must be near the driver when source termination is intended;
- switching hot loop must be compact;
- crystal/oscillator loop must be compact;
- current-sense routing must avoid load-current error;
- RF matching parts must form a controlled short structure;
- antenna keepout must be preserved;
- sensor exposure must remain mechanically valid;
- heat sources must be separated from temperature-sensitive circuitry;
- assembly access must be preserved.

The optimizer searches **inside** these constraints rather than trying to rediscover their meaning from wire length.

---

## 18.3 Placement objective

Placement should not be optimized by wire length alone.

Candidate scoring may include:

- route feasibility;
- congestion;
- critical-path geometry;
- estimated loop area;
- PDN path length;
- decoupling relationship;
- sensitive/aggressor proximity;
- predicted via count;
- thermal spacing;
- assembly margin;
- mechanical margin.

---

# 19. Routing strategy

Use a hybrid routing architecture.

## 19.1 Critical topology planner

Reserve deterministic/special treatment for structures whose topology itself matters:

- clock trees;
- controlled source termination;
- switching loops;
- current-sense Kelvin paths;
- differential pairs;
- BGA/QFN escapes;
- RF launches;
- matched electrical paths;
- sensitive analog routes;
- unusual mechanical geometry.

Critical routes may be explicitly generated when there is effectively no useful search freedom.

---

## 19.2 General autorouter

Use the routing engine for ordinary connectivity under declared constraints.

Routing attempts should:

- operate on candidate boards;
- never silently alter the authoritative board;
- record the source digest;
- record the routing plan;
- record tool identity/version;
- record configuration;
- record output candidates;
- record DRC;
- record acceptance metrics;
- avoid hidden retry loops.

---

## 19.3 Length and time tuning

Length matching is only a proxy for electrical timing.

The toolkit should prefer:

```text
electrical path delay / skew requirement
        ↓
router-level length targets where valid
        ↓
post-route electrical-path measurement
```

The final verification applies to the electrical requirement, not merely to a net-length number.

---

# 20. Physical PCB verification before extraction

After placement/routing and before expensive simulation, run cheap deterministic checks first.

Examples:

- KiCad DRC;
- schematic parity;
- unconnected nets;
- topology rules;
- placement constraints;
- routing-layer constraints;
- via budgets;
- copper-to-edge;
- creepage/clearance where applicable;
- package spacing;
- courtyard/interference checks;
- mask rules;
- manufacturing constraints;
- critical-net topology;
- reference-plane continuity proxies;
- assembly restrictions.

There is no reason to run expensive EM on a board that still has a basic DRC or topology failure.

---

# 21. Parasitic extraction

Parasitic analysis should proceed in increasing fidelity and cost.

## 21.1 Tier 1 — geometry and closed-form/analytic extraction

From authoritative PCB geometry and the physical stackup:

- conductor length;
- cross-section;
- DC resistance;
- approximate capacitance;
- approximate inductance;
- characteristic impedance;
- propagation delay;
- via transitions;
- reference-plane context;
- parallel-run geometry;
- unreferenced length.

Every result must state the model used and unsupported geometry.

---

## 21.2 Tier 2 — quasi-static extraction

A higher-fidelity backend should eventually extract:

- resistance per unit length;
- capacitance per unit length;
- inductance per unit length;
- mutual capacitance;
- mutual inductance;
- odd/even-mode impedance;
- differential/common-mode behavior;
- coupling;
- via parasitics;
- arbitrary cross-section effects.

Results should use the same claim/evidence interface as analytic extraction.

---

## 21.3 Tier 3 — targeted full-wave extraction

Use a full-wave backend such as openEMS only where the simpler model is insufficient and the answer may change a design decision.

Do not begin with whole-board full-wave simulation.

Good candidates:

- connector launches;
- via transitions;
- high-speed differential discontinuities;
- RF structures;
- coupled aggressor/victim regions;
- unusual return-path transitions;
- package-to-connector paths.

Flow:

```text
authoritative PCB geometry
        ↓
region / ElectricalPath selection
        ↓
EM submodel
        ├── traces
        ├── vias
        ├── nearby copper
        ├── planes
        ├── dielectric
        └── ports
        ↓
solver
        ↓
Touchstone / field data
        ↓
analysis
        ├── TDR
        ├── impedance
        ├── group delay
        ├── insertion loss
        ├── return loss
        └── crosstalk
        ↓
claim / gate
```

The hard problem is not calling the solver; it is trustworthy geometry translation, meshing, port definition, reference definition, boundary conditions, frequency range, and de-embedding.

The backend must refuse release-grade claims when those cannot be established.

---

# 22. Post-layout simulation

After parasitic extraction, applicable pre-layout scenarios should be rerun with the physical interconnect substituted.

This is a second simulation stage, not merely another unrelated report.

The useful comparison is:

```text
pre-layout model
        vs
post-layout model
```

The agent should be able to ask:

- Did PCB resistance materially change the rail margin?
- Did via inductance create ringing?
- Did trace delay reduce setup/hold margin?
- Did real clock-tree skew exceed the original budget?
- Did coupling inject unacceptable error into an analog channel?
- Did the decoupling-loop geometry degrade transient behavior?
- Did the routed impedance invalidate the nominal termination?
- Did a switching loop become too inductive?

Post-layout simulation can therefore expose failures that were impossible to see at schematic stage.

---

## 22.1 Electrical/digital bridge

Long-term target:

```text
RTL / behavioral transition
        ↓
electrical output-driver model
        ↓
package model where available
        ↓
extracted PCB interconnect
        ↓
receiver electrical model
        ↓
threshold-crossing event
        ↓
digital timing assertion
```

Timing assertions should use receiver threshold-crossing time when the required models exist, not ideal RTL edge time.

---

# 23. Power integrity

Power integrity deserves an explicit analysis path.

Possible quantities:

- source-to-load DC resistance;
- distribution voltage drop;
- via/current bottlenecks;
- plane spreading resistance;
- decoupling-loop inductance;
- plane inductance;
- local supply impedance;
- PDN impedance versus frequency;
- anti-resonances;
- transient droop.

PI results should eventually feed both simulation and placement/routing optimization.

---

# 24. Thermal analysis

Thermal behavior should be a first-class verification domain rather than only a placement heuristic.

Depending on capability and available evidence:

- component dissipation;
- copper spreading;
- via thermal conductance;
- junction-to-board/package thermal paths;
- ambient assumptions;
- airflow assumptions;
- heat-source proximity;
- temperature-sensitive component error;
- regulator/MOSFET thermal margin.

A simple thermal estimate must be labeled as such.

A board should not claim a specific maximum junction temperature merely from a generic package θJA number when the actual boundary conditions do not match its validity.

Physical prototype testing may remain necessary for release confidence on thermally demanding designs.

---

# 25. Assembly and DFA

The target is a **PCBA**, not only a bare PCB.

The architecture should have explicit assembly checks or board-owned constraints for items such as:

- component spacing;
- courtyards;
- pick-and-place access;
- placement side;
- package orientation;
- paste-mask design;
- thermal-pad paste segmentation;
- via-in-pad process;
- hand-soldered parts;
- DNP handling;
- component height;
- fiducials;
- board handling;
- reflow compatibility;
- moisture-sensitive components;
- acoustic/optical openings;
- connector insertion access.

JLCPCB's online assembly preview may expose information that cannot be fully validated locally. Such steps should be recorded as external/manual release dependencies rather than silently assumed.

---

# 26. Verification-method classification

Every significant requirement should identify the strongest verification method currently available.

Useful classes include:

```text
STATIC
GEOMETRY
ANALYTIC
CIRCUIT_SIM
DIGITAL_SIM
EXTRACTED
EM_SIM
THERMAL_SIM
MANUFACTURING_CHECK
PHYSICAL_TEST
DOCUMENTATION
```

A requirement may require more than one class.

Examples:

```text
USB differential impedance
    → GEOMETRY + EXTRACTED
    → EM_SIM for suspicious discontinuities

buck converter control-loop stability
    → CIRCUIT_SIM
    → PHYSICAL_TEST if model fidelity is inadequate

IEC ESD survival
    → GEOMETRY / protection review
    → PHYSICAL_TEST for compliance claim
```

The agent should be rewarded for correctly saying **physical validation is still required** when simulation cannot establish the requirement.

---

# 27. Design iteration

A failure should identify the design variables most likely responsible.

Possible variables:

- component;
- topology;
- resistor/capacitor/inductor value;
- regulator;
- termination;
- decoupling;
- placement;
- orientation;
- stackup;
- trace width;
- trace spacing;
- routing layer;
- via type;
- via count;
- routing corridor;
- return-path geometry;
- power-plane geometry;
- thermal copper;
- requirement assumption.

The iteration controller should route the failure upstream to the earliest stage that can actually fix it.

Example:

```text
post-layout clock overshoot
        ↓
is routing topology wrong?
        ├── yes → reroute / replace physical candidate
        └── no
              ↓
is source termination inadequate?
        ├── yes → schematic value change
        │         ↓
        │       rerun pre-layout simulation
        │         ↓
        │       regenerate PCB
        └── no → improve model / targeted extraction
```

Do not force every post-layout failure into a routing-only fix.

---

# 28. Electrical quality as optimization feedback

The long-term closed loop is:

```text
candidate
    ↓
route
    ↓
cheap physical checks
    ↓
analytic extraction
    ↓
selected simulation
    ↓
score
    ├── poor → modify candidate/design variable
    └── good → retain
```

Potential hard constraints:

- schematic connectivity;
- DRC;
- mechanical constraints;
- fabrication constraints;
- required topology;
- safety constraints;
- mandatory timing;
- mandatory power limits.

Potential soft objectives:

- congestion;
- via count;
- route length;
- electrical-path delay;
- skew;
- impedance error;
- coupling;
- loop inductance;
- PDN impedance;
- thermal margin;
- manufacturing margin;
- assembly margin.

The optimizer should improve **electrical quality**, not merely connectivity.

---

# 29. Generic electrical-quality metrics

The toolkit should report comparable revision-to-revision metrics.

## 29.1 Interconnect

Per critical ElectricalPath:

- total copper length;
- layer distribution;
- via count;
- via vertical length;
- DC resistance;
- capacitance;
- inductance;
- characteristic impedance;
- propagation delay;
- skew;
- reference-plane changes;
- unreferenced length;
- model completeness.

---

## 29.2 Coupling

For sensitive structures:

- nearest-neighbor spacing;
- parallel-run length;
- mutual capacitance;
- mutual inductance;
- NEXT/FEXT;
- S31/S41 where extracted.

---

## 29.3 Power

Per rail:

- distribution resistance;
- distribution inductance;
- decoupling-loop inductance;
- regulator-to-load impedance;
- PDN impedance versus frequency;
- transient droop;
- current bottlenecks.

---

## 29.4 Signal integrity

For selected interfaces:

- receiver rise/fall time;
- overshoot;
- undershoot;
- ringing;
- threshold-crossing time;
- setup/hold margin;
- TDR discontinuities;
- return loss;
- insertion loss;
- eye margin where meaningful.

---

## 29.5 Implementation quality

- unrouted nets;
- routing retries;
- via count;
- routed copper;
- congestion;
- DRC margin;
- fabrication-rule margin;
- assembly margin;
- optimizer effort;
- simulation cost;
- extraction cost;
- unresolved assumptions;
- unsupported claims.

---

# 30. Autonomous action policy

A result should carry enough policy for the agent to know what it permits.

Representative policy states:

```text
nominal-design-allowed
provisional-layout-allowed
analysis-only
requires-additional-evidence
requires-human-review
fabrication-ready
release-ready
blocked
```

The policy should answer questions such as:

- may the agent choose a nominal track width?
- may it reserve routing space?
- may it continue placement?
- may it continue routing?
- may it select a JLCPCB process?
- may it mark an electrical requirement satisfied?
- may it generate fabrication outputs?
- may the release gate pass?

A positive result at one stage should not automatically authorize all later stages.

---

# 31. Branches, candidates, and reproducibility

Substantial alternatives should remain isolated.

Principles:

- `main` represents a deliberately accepted state;
- architecture changes occur on branches;
- routing/placement attempts may use reproducible candidates;
- the authoritative board is not silently modified by an optimizer;
- every candidate records its source state and tool provenance;
- accepted candidates are promoted deliberately;
- generated evidence belongs to the state that produced it;
- submodule pins must resolve to commits available from their configured remotes before the parent state is considered portable.

A later failure should be reproducible from the recorded design state.

---

# 32. Release and fabrication closure

The current toolkit treats a release as a Git tag over a validated commit.

The autonomous agent may prepare a release, but release identity and engineering proof should remain distinct.

A design becomes release-ready only when:

- required schematic checks pass;
- required PCB checks pass;
- required electrical constraints are evaluated;
- mandatory unresolved assumptions are closed;
- required simulation/extraction evidence exists;
- required JLCPCB process constraints are established;
- fabrication selections are bound;
- assembly constraints are addressed;
- generated outputs correspond to the validated design state;
- model/tool/process provenance is adequate;
- the working tree and submodules satisfy release policy;
- unresolved unsupported claims are either explicitly permitted or blocking according to board policy.

Fabrication artifacts should be reproducible and tied to the exact design source closure.

A release should never depend on a live web lookup changing the verdict.

---

# 33. Parallel development strategy for the toolkit

The toolkit self-test is valuable but should not dominate every isolated change.

Use focused workstreams.

## Track A — unified evidence model

- migrate remaining timing/simulation producers into the shared claim model;
- preserve exact/bound/approximate/unknown semantics;
- remove duplicate verdict logic where possible.

## Track B — component and package provenance

- package pin mapping;
- symbol/footprint consistency;
- simulation-model terminal mapping;
- component-source registry;
- part-selection evidence.

## Track C — pre-layout simulation

- schematic-derived scenario generation;
- ngspice scenario expansion;
- power and analog scenarios;
- schematic-stage model coverage;
- iteration results suitable for the agent.

## Track D — digital simulation

- behavioral board contracts;
- Verilator execution;
- FPGA/MCU/host/peripheral boundary models;
- substitution of production RTL.

## Track E — parasitic extraction

- geometry extraction;
- R/L/C;
- propagation;
- via models;
- coupling;
- ElectricalPath integration.

## Track F — placement optimization

- semantic placement schema;
- candidate generator;
- optimization;
- legalization;
- route-aware scoring.

## Track G — routing modernization

- differential routing;
- buses;
- fanout;
- propagation-time-aware tuning;
- ElectricalPath-to-router constraint mapping.

## Track H — power integrity

- DC network extraction;
- decoupling-loop analysis;
- PDN impedance;
- transient scenario integration.

## Track I — targeted EM

- geometry exporter;
- ports;
- meshing;
- fixtures;
- Touchstone import;
- TDR/crosstalk/S-parameter claims.

## Track J — thermal / assembly

- basic thermal estimates;
- thermal provenance;
- assembly constraints;
- JLCPCB assembly validation where locally establishable.

## Track K — autonomous integration

- end-to-end board-development scenarios;
- failure-to-design-variable mapping;
- branch/candidate orchestration;
- release evidence.

---

# 34. Test cadence

Preferred cadence:

```text
focused unit tests
    ↓
workstream integration tests
    ↓
consumer-board tests
    ↓
cross-workstream integration
    ↓
full toolkit selftest
    ↓
end-to-end autonomous design validation
```

Independent simulations, extraction jobs, and candidate evaluations should run concurrently where doing so is deterministic and safe.

The full self-test should run at coherent integration points, not after every local edit.

---

# 35. Capability roadmap

## Phase 1 — evidence and policy convergence

Stabilize:

- one claim/evidence model;
- provenance;
- bounds/unknown semantics;
- design-stage vs release-stage policy.

---

## Phase 2 — component and schematic confidence

Add or strengthen:

- part-selection records;
- package/pin verification;
- symbol/footprint/model correspondence;
- schematic static gates;
- generated-design parity.

---

## Phase 3 — pre-layout simulation gate

Build out:

- generic scenario generation;
- ngspice coverage;
- power scenarios;
- analog scenarios;
- mixed behavioral scenarios;
- agent-readable failure diagnosis.

This phase should make **schematic simulation occur before detailed PCB design** whenever the models support meaningful evaluation.

---

## Phase 4 — analytic parasitic extraction

Expand:

- resistance;
- capacitance;
- inductance;
- propagation delay;
- impedance;
- vias;
- coupling approximations;
- ElectricalPath totals.

Make these results directly consumable by post-layout simulation.

---

## Phase 5 — placement and routing optimization

Introduce:

- semantic placement;
- search-based placement;
- route-in-loop scoring;
- differential/bus routing;
- time-aware tuning.

---

## Phase 6 — post-layout mixed-fidelity simulation

Connect:

- functional digital models;
- SPICE;
- package models where available;
- extracted PCB interconnect;
- timing assertions;
- SI assertions;
- power assertions.

Reuse applicable pre-layout scenarios so physical effects are measurable as deltas.

---

## Phase 7 — higher-fidelity PI / quasi-static / EM

Add stronger solvers only for problems where the simpler evidence is inadequate.

Do not add a backend dispatch abstraction until a real backend exists.

---

## Phase 8 — optimization against electrical simulation

Use extraction/simulation results to modify:

- component selection;
- placement;
- routing;
- stackup;
- termination;
- decoupling;
- topology.

---

## Phase 9 — PCBA closure

Add stronger:

- thermal validation;
- assembly validation;
- test-point/access checks;
- production evidence;
- release closure.

---

# 36. Long-term autonomous PCBA development loop

```text
1. Product brief
        ↓
2. Interpret brief
        ├── user requirements
        ├── derived requirements
        ├── assumptions
        └── verification plan
        ↓
3. Architecture exploration
        ↓
4. Component selection + source/model acquisition
        ↓
5. Package / symbol / footprint / model mapping
        ↓
6. Schematic generation
        ↓
7. Static schematic verification
        ├── ERC
        ├── connectivity
        ├── ratings
        ├── voltage domains
        ├── pin mappings
        └── generated-design parity
        ↓
8. Pre-layout simulation
        ├── SPICE
        ├── digital / behavioral
        ├── power
        └── functional scenarios
        ↓
9. Schematic/architecture acceptable?
        │
        ├── no → modify architecture/components/values/models
        │         and return upstream
        │
        └── yes or explicitly provisional
                  ↓
10. Select JLCPCB process + stackup
                  ↓
11. Freeze physical electrical intent
                  ├── ElectricalPaths
                  ├── impedance
                  ├── timing
                  ├── topology
                  ├── PI
                  ├── thermal
                  └── assembly
                  ↓
12. Functional floorplan
                  ↓
13. Placement optimization
                  ↓
14. Critical topology / fanout generation
                  ↓
15. General routing
                  ↓
16. Length / time tuning
                  ↓
17. Cheap physical checks
                  ├── DRC
                  ├── parity
                  ├── topology
                  ├── placement
                  ├── manufacturing
                  └── assembly
                  ↓
18. Analytic parasitic extraction
                  ↓
19. Post-layout simulation
                  ├── extracted interconnect
                  ├── power
                  ├── analog
                  ├── digital timing
                  └── mixed-signal
                  ↓
20. Higher-fidelity analysis required?
        │
        ├── yes → quasi-static / PI / targeted EM / thermal
        │
        └── no
                  ↓
21. Requirements established?
        │
        ├── no
        │    ↓
        │  classify responsible variable
        │    ├── assumption/requirement → return to interpretation
        │    ├── component/topology/value → return to schematic
        │    ├── stackup → return to process selection
        │    ├── placement → regenerate candidate
        │    ├── routing → regenerate candidate
        │    └── model/evidence → improve verification
        │
        └── yes
                  ↓
22. Build fabrication + assembly outputs
                  ↓
23. Validate exact outputs
                  ↓
24. Release-check
                  ↓
25. Deliberate Git release tag
```

The board should graduate from one confidence level to the next only when the corresponding evidence exists.

---

# 37. Guiding principles

1. **The AI owns engineering intent; search engines own most geometric search.**
2. **Native KiCad files are authoritative for the realized schematic and PCB.**
3. **Generated designs are allowed, but generation does not replace independent parity checks.**
4. **User requirements, derived requirements, assumptions, and design decisions must remain distinguishable.**
5. **Component selection is part of electrical design, not merely BOM filling.**
6. **Model terminals, schematic pins, footprint pads, and physical package pins must correspond before simulation can validate hardware.**
7. **Unknown is not PASS.**
8. **An omitted contribution is not zero.**
9. **Models must carry provenance, applicability, conditions, and omissions.**
10. **Simulation should use mixed fidelity rather than inventing nonexistent detailed models.**
11. **Run the strongest meaningful schematic-level simulation before detailed PCB design.**
12. **A pre-layout PASS validates only the modeled circuit under the stated interconnect assumptions.**
13. **After layout, rerun applicable scenarios using geometry-derived interconnect.**
14. **Electrical requirements belong to complete ElectricalPaths when net boundaries do not match the physical requirement.**
15. **Placement and routing should be optimized against electrical quality, not just connectivity.**
16. **Expensive physics should be targeted where it can change a decision.**
17. **Cheap deterministic failures should be found before expensive simulation.**
18. **Every failure should point toward design variables the agent can modify.**
19. **A post-layout problem may require a schematic change; do not force every failure into routing.**
20. **Fabrication and assembly constraints are distinct from nominal electrical design.**
21. **A useful provisional result is not automatically a release result.**
22. **Live network state must not change release validation.**
23. **The toolkit should remain board-agnostic; board-specific policy belongs to consumer repositories.**
24. **The current manufacturing target is JLCPCB; do not invent a multi-fabricator abstraction without a real need and implementation.**
25. **An architecture document may describe future capability, but production code must not pretend an unimplemented backend exists.**
26. **Git owns history and release identity; engineering tooling owns evidence that a tagged state is acceptable.**
27. **The final authority for behavior that simulation cannot establish is physical test, and the system should say so explicitly.**

---

# 38. Desired end state

The desired system can accept an unfamiliar PCBA brief and autonomously produce a traceable chain:

```text
human intent
    ↓
engineering requirements
    ↓
recorded assumptions
    ↓
component and architecture rationale
    ↓
verified schematic
    ↓
pre-layout electrical evidence
    ↓
physical constraints
    ↓
optimized PCB candidate
    ↓
verified physical implementation
    ↓
extracted parasitics
    ↓
post-layout electrical evidence
    ↓
targeted higher-fidelity analysis
    ↓
documented residual uncertainty
    ↓
reproducible fabrication / assembly artifacts
    ↓
release evidence
```

Success is not "the files look plausible."

Success is that the agent can explain, with machine-verifiable evidence, **what it believes about the board, why it believes it, which assumptions remain, which physical effects were evaluated, which could not be evaluated, and why the exact design state is suitable—or not suitable—for fabrication and release.**

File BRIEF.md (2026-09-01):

# PCBA_USB_C_UART_Debugger — USB-C UART Debug Adapter
## Design brief

Create a USB-C to 3.3 V UART debug adapter. It must be a USB 2.0 Full-Speed device, bus-powered, and expose TX, RX, GND, 3V3 reference, and optional RTS/CTS on a 0.1-inch or compact locking header. Include the correct USB-C device-side CC network, USB ESD protection close to the connector, local decoupling, and clearly separated USB and target-side connectors. Choose a commonly available USB-UART bridge. Prefer two layers, but route D+/D- as a deliberate differential pair and document any impedance approximation.

## Functional requirements

- Enumerates as a Full-Speed (12 Mbit/s) USB 2.0 device presenting one asynchronous serial port; driver support and baud range documented.
- Target-side signals are 3.3 V CMOS referenced to the shared GND pin, and TX, RX and any fitted RTS/CTS are labelled from a stated point of view.

## Power and rails

- Bus-powered only: no battery, no required target-side supply, no current sourced onto VBUS.
- Stays within the USB 2.0 unconfigured, configured and suspend current limits and the inrush capacitance limit.
- The 3.3 V rail holds tolerance across the permitted VBUS range and full load, with its source and current capability documented.
- Local decoupling at every supply pin on a short ground return, plus bulk capacitance on the rail.

## Connectors and pinout

- CC1 and CC2 each present an independent Rd for a sink taking default USB power, so orientation resolves either way; neither is tied to the other or to VBUS.
- The target header carries at least TX, RX, GND and 3V3, pin 1 marked, functions on the silkscreen, and the pinout documented.
- USB and target connectors sit on separated, visually distinct parts of the outline, neither obstructing access to the other.

## Signal integrity and layout

- D+/D- targets the USB 2.0 nominal differential impedance; where the stackup cannot reach it, the calculated value, stackup parameters and method are recorded.
- The pair runs over uninterrupted ground its whole length, with no split, gap or crossing trace beneath it and documented clearance to other nets.
- Pair length is short and documented, layer transitions minimised and symmetric, intra-pair skew matched to a stated tolerance, no stubs.
- Two layers unless a documented reason requires more; the stackup is recorded either way.

## Protection and robustness

- ESD protection covers D+ and D-, sits between the receptacle and everything downstream with the shortest practical ground return, and adds no more capacitance than full-speed edge and eye limits allow.
- Coverage of VBUS, CC and shield ground is a documented decision, and any CC protection leaves the Rd thresholds undisturbed.
- Nothing is damaged when the target drives TX, RX or 3V3 with VBUS absent, and hot-plugging the target does not drop the host connection.

## Test and bring-up

- A TX-to-RX loopback at the target header exercises the whole data path with no target attached, and VBUS, 3V3, GND, D+ and D- are probeable.
- Any on-chip descriptor programming interface the bridge needs is reachable when assembled.

## Open choices

- The USB-UART bridge, subject to Full-Speed USB 2.0 operation, 3.3 V logic I/O, the VBUS current budget, RTS/CTS if fitted, and documented availability and drivers.
- Header style — 0.1-inch pitch or compact locking — and whether RTS/CTS is fitted at all.
- Whether 3V3 is a reference only or may source current to the target, with its budget and any limiting; the rail's source follows.

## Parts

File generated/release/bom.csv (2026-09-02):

Quantity | Designator | Comment | Footprint | LCSC Part #
7 | C1,C3,C5,C7,C9,C10,C11 | 4.7uF | Capacitor_SMD:C_0603_1608Metric | C19666
4 | C2,C4,C6,C8 | 100nF | Capacitor_SMD:C_0603_1608Metric | C14663
1 | D1 | USBLC6-2SC6 | Package_TO_SOT_SMD:SOT-23-6 | C7519
1 | J1 | TYPE-C-31-M-12 | Connector_USB:USB_C_Receptacle_HRO_TYPE-C-31-M-12 | C165948
1 | J2 | KH-2.54PH180-1X6P-L11.5 | Connector_PinHeader_2.54mm:PinHeader_1x06_P2.54mm_Vertical | C2905486
2 | Q1,Q2 | AO3401A | Package_TO_SOT_SMD:SOT-23 | C15127
1 | Q3 | AO3400A | Package_TO_SOT_SMD:SOT-23 | C20917
2 | R1,R2 | 5.1k | Resistor_SMD:R_0603_1608Metric | C23186
1 | R3 | 1k | Resistor_SMD:R_0603_1608Metric | C21190
2 | R4,R6 | 100k | Resistor_SMD:R_0603_1608Metric | C25803
1 | R5 | 220k | Resistor_SMD:R_0603_1608Metric | C22961
1 | R7 | 10k | Resistor_SMD:R_0603_1608Metric | C25804
4 | R8,R9,R10,R11 | 220R | Resistor_SMD:R_0603_1608Metric | C22962
1 | U1 | CP2102N-A02-GQFN28R | UsbCUartDebugger:QFN-28-1EP_5x5mm_P0.5mm_CP2102N | C964632
1 | U2 | XC6206P332PR-G | Package_TO_SOT_SMD:SOT-89-3 | C526275

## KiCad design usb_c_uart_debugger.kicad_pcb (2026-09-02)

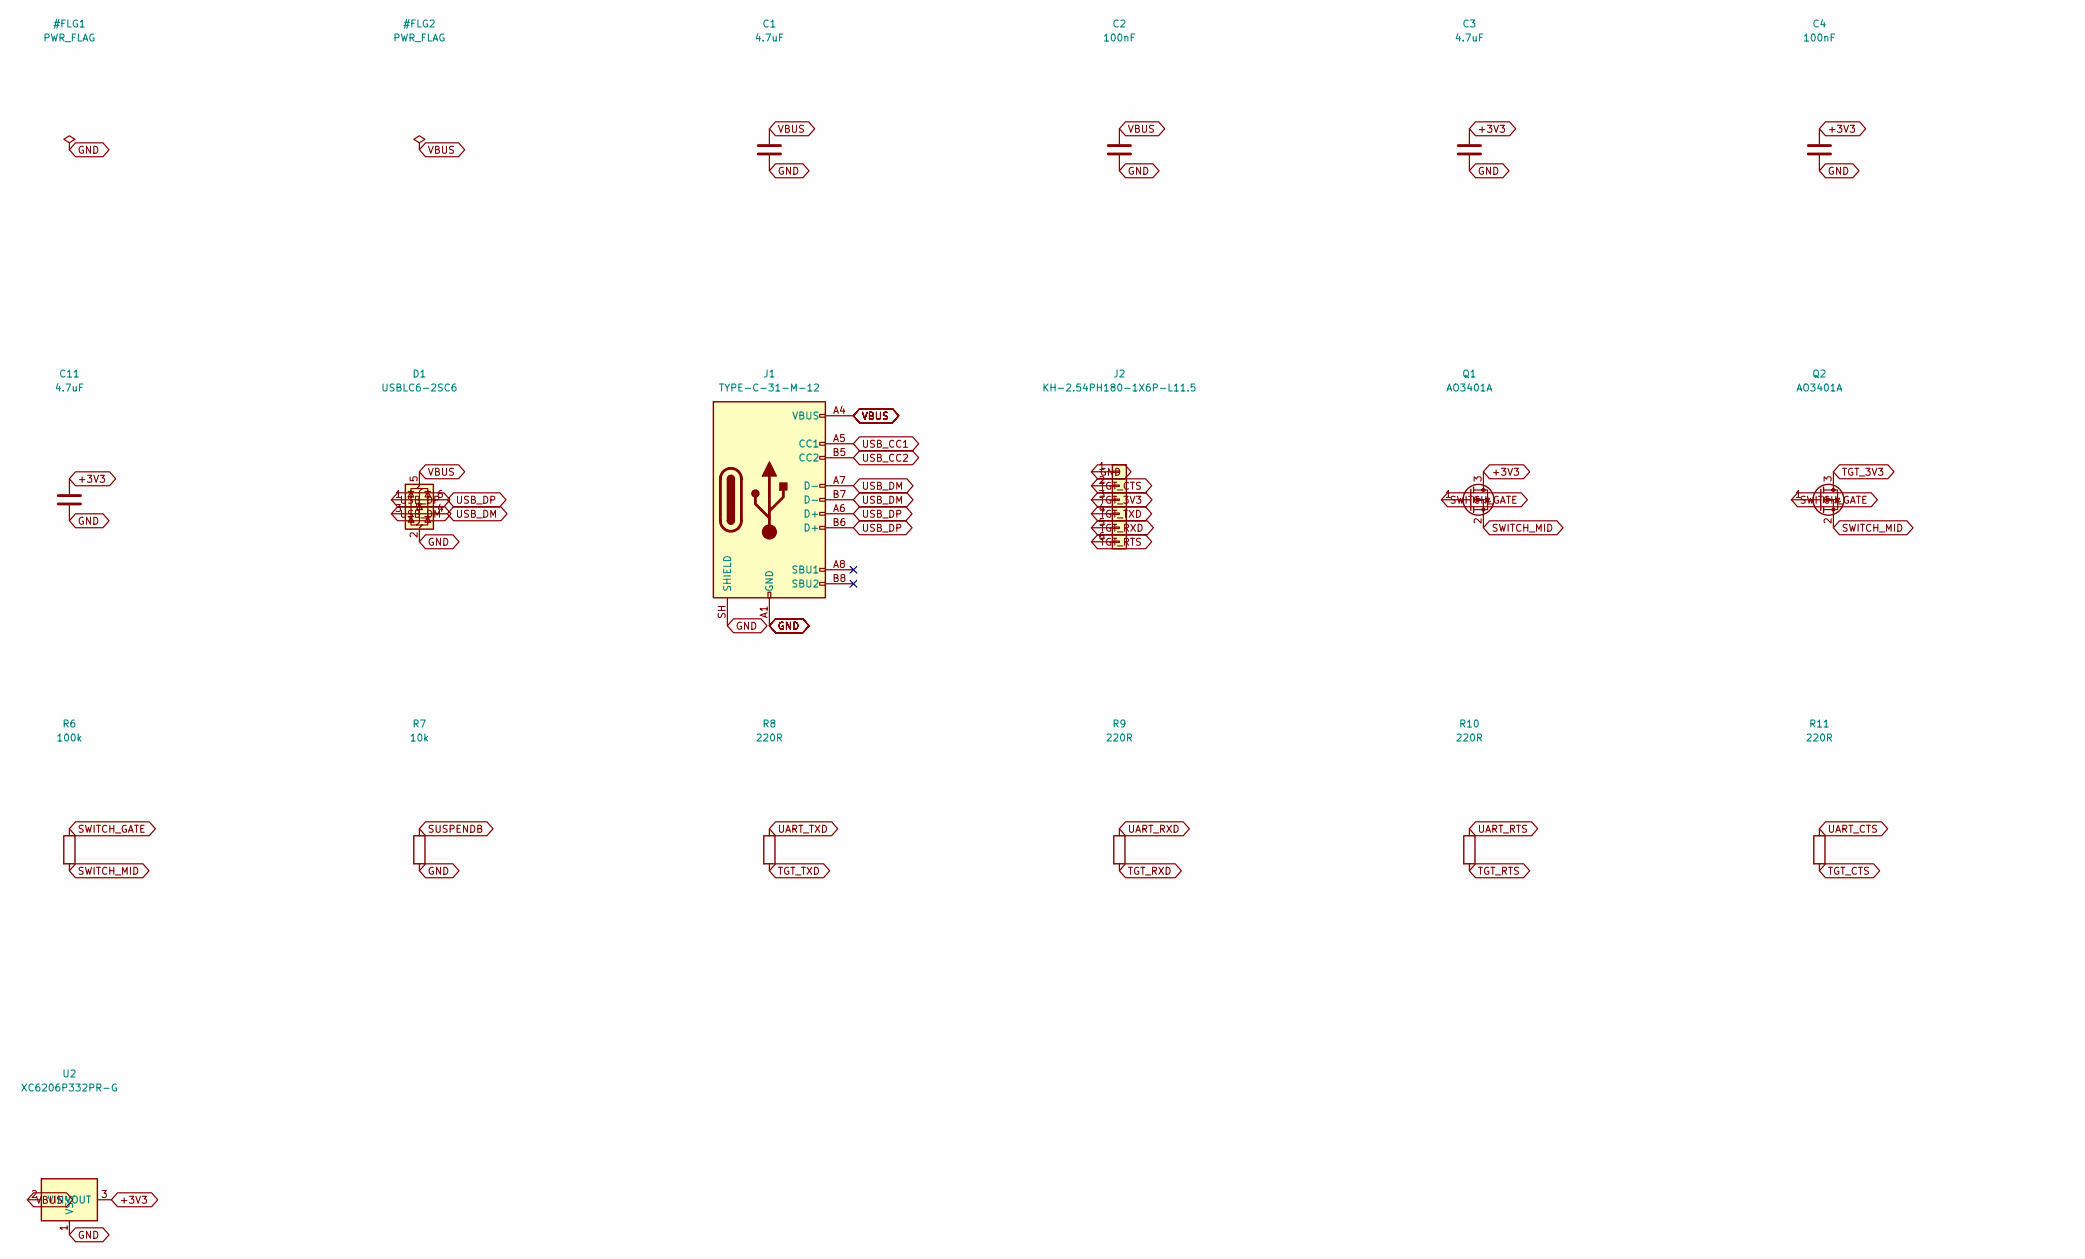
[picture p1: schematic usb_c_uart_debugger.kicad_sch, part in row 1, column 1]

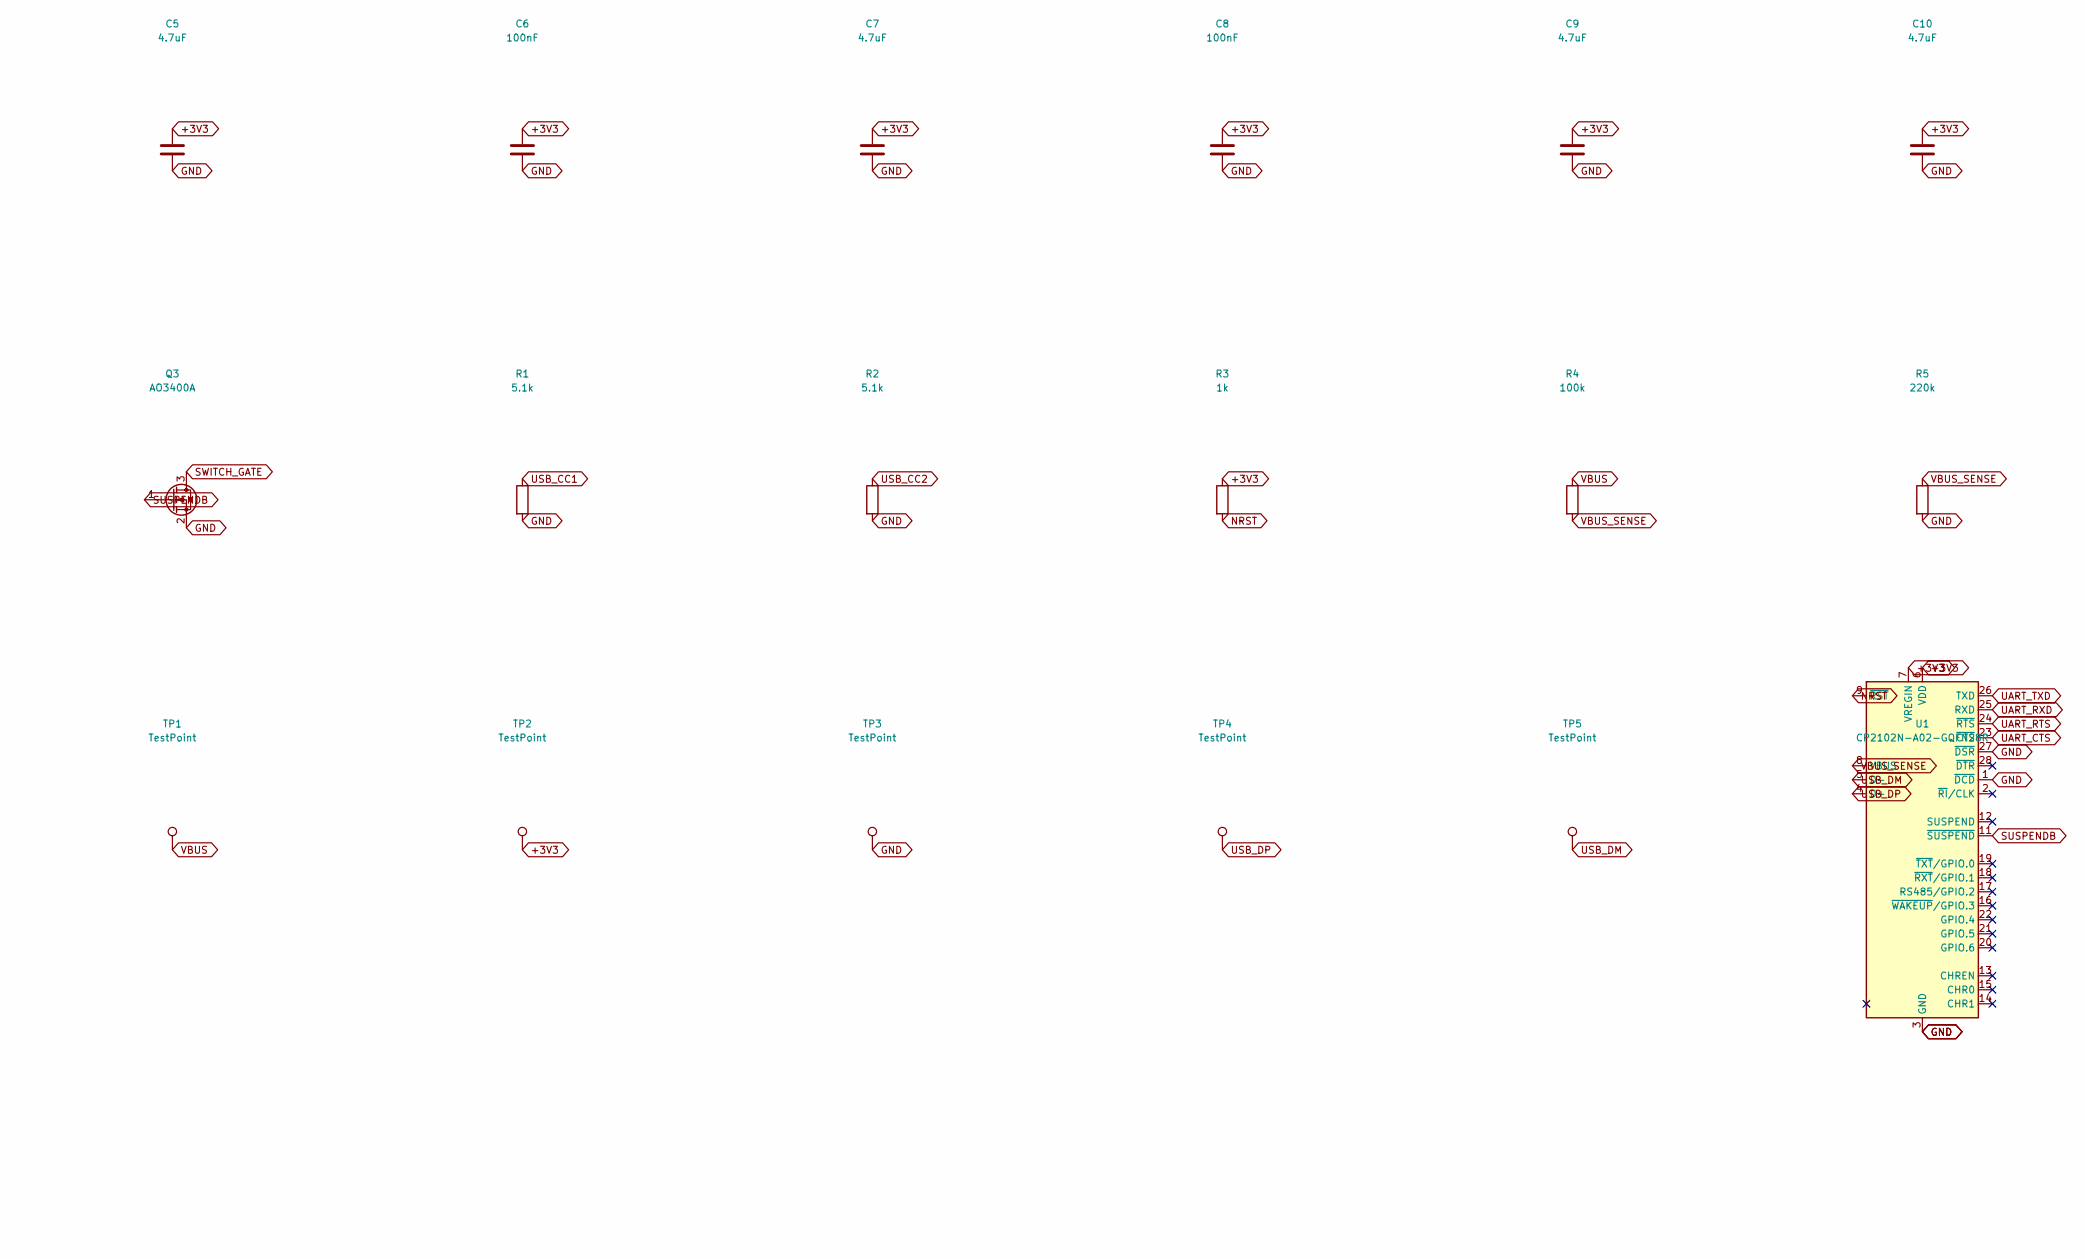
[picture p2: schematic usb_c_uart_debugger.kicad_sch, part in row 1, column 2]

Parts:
C1, C3, C5, C7, C9, C10, C11: 4.7uF; C_0603_1608Metric; MPN CL10A475KO8NNNC; LCSC C19666
C2, C4, C6, C8: 100nF; C_0603_1608Metric; MPN CC0603KRX7R9BB104; LCSC C14663
D1: USBLC6-2SC6; SOT-23-6; MPN USBLC6-2SC6; LCSC C7519
J1: TYPE-C-31-M-12; USB_C_Receptacle_HRO_TYPE-C-31-M-12; MPN TYPE-C-31-M-12; LCSC C165948
J2: KH-2.54PH180-1X6P-L11.5; PinHeader_1x06_P2.54mm_Vertical; MPN KH-2.54PH180-1X6P-L11.5; LCSC C2905486
Q1, Q2: AO3401A; SOT-23; MPN AO3401A; LCSC C15127
Q3: AO3400A; SOT-23; MPN AO3400A; LCSC C20917
R1, R2: 5.1k; R_0603_1608Metric; MPN 0603WAF5101T5E; LCSC C23186
R3: 1k; R_0603_1608Metric; MPN 0603WAF1001T5E; LCSC C21190
R4, R6: 100k; R_0603_1608Metric; MPN 0603WAF1003T5E; LCSC C25803
R5: 220k; R_0603_1608Metric; MPN 0603WAF2203T5E; LCSC C22961
R7: 10k; R_0603_1608Metric; MPN 0603WAF1002T5E; LCSC C25804
R8, R9, R10, R11: 220R; R_0603_1608Metric; MPN 0603WAF2200T5E; LCSC C22962
TP1, TP2, TP3, TP4, TP5: TestPoint; TestPoint_Pad_D1.0mm
U1: CP2102N-A02-GQFN28R; QFN-28-1EP_5x5mm_P0.5mm_CP2102N; MPN CP2102N-A02-GQFN28R; LCSC C964632
U2: XC6206P332PR-G; SOT-89-3; MPN XC6206P332PR-G; LCSC C526275

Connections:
+3V3: C3.1, C4.1, C5.1, C6.1, C7.1, C8.1, C9.1, C10.1, C11.1, Q1.3 (D), R3.1, TP2.1, U1.6 (VDD), U1.7 (VREGIN), U2.3 (VOUT)
GND: C1.2, C2.2, C3.2, C4.2, C5.2, C6.2, C7.2, C8.2, C9.2, C10.2, C11.2, D1.2 (GND), J1.A1 (GND), J1.A12 (GND), J1.B1 (GND), J1.B12 (GND), J1.SH (SHIELD), J2.1, Q3.2 (S), R1.2, R2.2, R5.2, R7.2, TP3.1, U1.1 (~DCD), U1.3 (GND), U1.27 (~DSR), U1.29 (GND), U2.1 (VSS)
NRST: R3.2, U1.9 (~RST)
SUSPENDB: Q3.1 (G), R7.1, U1.11 (~SUSPEND)
SWITCH_GATE: Q1.1 (G), Q2.1 (G), Q3.3 (D), R6.1
SWITCH_MID: Q1.2 (S), Q2.2 (S), R6.2
TGT_3V3: J2.3, Q2.3 (D)
TGT_CTS: J2.2, R11.2
TGT_RTS: J2.6, R10.2
TGT_RXD: J2.5, R9.2
TGT_TXD: J2.4, R8.2
UART_CTS: R11.1, U1.23 (~CTS)
UART_RTS: R10.1, U1.24 (~RTS)
UART_RXD: R9.1, U1.25 (RXD)
UART_TXD: R8.1, U1.26 (TXD)
USB_CC1: J1.A5 (CC1), R1.1
USB_CC2: J1.B5 (CC2), R2.1
USB_DM: D1.3 (I/O2), D1.4 (I/O2), J1.A7 (D-), J1.B7 (D-), TP5.1, U1.5 (D-)
USB_DP: D1.1 (I/O1), D1.6 (I/O1), J1.A6 (D+), J1.B6 (D+), TP4.1, U1.4 (D+)
VBUS: C1.1, C2.1, D1.5 (VBUS), J1.A4 (VBUS), J1.A9 (VBUS), J1.B4 (VBUS), J1.B9 (VBUS), R4.1, TP1.1, U2.2 (VIN)
VBUS_SENSE: R4.2, R5.1, U1.8 (VBUS)

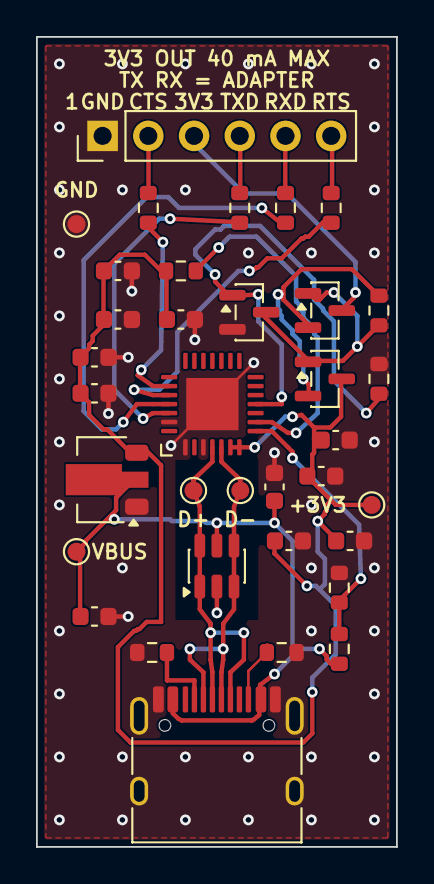
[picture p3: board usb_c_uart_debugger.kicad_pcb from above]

Board: 2 copper layers, 20.0 x 45.0 mm, 35 parts (0 on the bottom side), 21 nets.

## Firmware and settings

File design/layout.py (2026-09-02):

"""The board: outline, placement, pours, critical copper and silkscreen.

Board coordinates run x right and y UP from the lower-left corner, which is
the frame every dimension in this module is stated in. KiCad's own y runs
down, so the mapping is applied once, here.

The arrangement follows the signal. The receptacle is at the bottom edge and
the target header at the top, so the two connectors are on opposite ends of
the outline and neither can obstruct the other. Between them the data pair
runs straight up the middle - through its suppressor and into the bridge -
and everything else is arranged around that corridor rather than through it.

The back layer is one uninterrupted ground pour, which is the pair's
reference. The front layer is poured on ground too, but with a rule area
that keeps the pour out of a corridor either side of the pair: the impedance
and the delay this board reports come from a microstrip model, and a pour
running alongside the conductors at less than the dielectric thickness would
make that model describe a structure the board does not have.
"""
from __future__ import annotations

import json
import math
import os
import sys

from . import ksym, libraries, netlist

_TOOLKIT = os.path.join(
    os.path.dirname(os.path.dirname(os.path.abspath(__file__))),
    "tooling", "PCBA_AutoDesignAndTest")
if _TOOLKIT not in sys.path:
    sys.path.insert(0, _TOOLKIT)

from pcbqa import headless  # noqa: E402

headless.suppress_blocking_ui()

import pcbnew  # noqa: E402

REPO_ROOT = os.path.dirname(os.path.dirname(os.path.abspath(__file__)))
BOARD_PATH = os.path.join(REPO_ROOT, netlist.PROJECT_NAME + ".kicad_pcb")
PLACEMENT_PATH = os.path.join(REPO_ROOT, "constraints", "placement.json")

FOOTPRINT_SEARCH_PATHS = (
    os.path.join(REPO_ROOT, "library"),
    "/usr/share/kicad/footprints",
)

ORIGIN_MM = (30.0, 80.0)

BOARD_W_MM = 20.0
BOARD_H_MM = 45.0

EDGE_WIDTH_MM = 0.1
TRACK_WIDTH_MM = 0.25
CLEARANCE_MM = 0.15
EDGE_CLEARANCE_MM = 0.3
VIA_DIAMETER_MM = 0.6
VIA_DRILL_MM = 0.3
ZONE_INSET_MM = 0.5
#: The narrowest strip of pour the fabricator will etch, and so the
#: narrowest one this board asks for. Copper thinner than this is not
#: poured at all, which is why a strip of reference between two cuts
#: narrower than this is not reference.
ZONE_MIN_WIDTH_MM = 0.2

#: Where the receptacle sits. Its own courtyard reaches 4.15 mm in front of
#: its origin, and the board is cut there, so the shell's opening is at the
#: edge and a plug meets nothing before it.
RECEPTACLE_MM = (10.0, 4.15)

#: The receptacle's own land row, and the four data lands along it. The
#: offsets are the footprint's; they are restated here because the whole
#: launch geometry below is built from them.
RECEPTACLE_LAND_Y_MM = RECEPTACLE_MM[1] + 4.045
RECEPTACLE_LAND_HALF_MM = 0.725
DATA_LAND_OFFSET_MM = {"B7": -0.75, "A6": -0.25, "A7": 0.25, "B6": 0.75}

#: The pair, from the receptacle to the bridge.
#:
#: The four data lands alternate - D-, D+, D-, D+ - so the two links that
#: join each line's pair of lands are two nets with interleaved terminals on
#: the boundary of a simply connected region. That cannot be drawn on one
#: layer, so each line takes exactly one layer change, and both take the
#: same one. The four traces leave the land row straight, clearing the
#: neighbouring lands, and only then fan apart: a 0.6 mm via cannot stand
#: beside a conductor half a millimetre away.
PAIR_CENTRE_X_MM = 10.0
#: How far north each data land goes before it turns. High enough that the
#: two sink terminations' own escape passes underneath it: their lands are
#: further out along the same row and have nowhere else to go.
LAND_ESCAPE_Y_MM = 9.7
FANOUT_Y_MM = 10.4
FANOUT_X_MM = {"B7": -1.5, "A6": -0.35, "A7": 0.35, "B6": 1.5}
LINK_Y_MM = {"USB_DM": 11.0, "USB_DP": 11.9}

#: Where the pair spreads to pass through the suppressor, which puts one
#: conductor on each of its two protected paths, and where it spreads again
#: so a probe pad can stand on each conductor without the two touching.
SUPPRESSOR_MM = (10.0, 15.6)
SPREAD_Y_MM = 13.2
PROBE_DX_MM = 1.3
PROBE_Y_MM = 19.8
PROBE_LEAD_MM = 0.9
CONVERGE_Y_MM = 21.4

#: The suppressor's reference pin sits between the two protected paths, and
#: its supply pin does too, because that is where its package puts them. The
#: reference goes straight into the plane through a via; the supply costs
#: one crossing under one conductor, taken on the back layer at a declared
#: place rather than left to a router to find.
CLAMP_GROUND_VIA_Y_MM = 13.0
CLAMP_RAIL_VIA_Y_MM = 18.0
CLAMP_RAIL_EXIT_X_MM = 13.2

#: The two sink terminations leave lands boxed between a no-connect land and
#: the pair, in a gap no search can fit a conductor through at its own
#: clearance. There is no freedom in either, so both are drawn here: north
#: out of the land, west or east clear of the pair's fan-out, and on to the
#: resistor.
CC_ESCAPE_Y_MM = 9.25
CC_LAND_OFFSET_MM = {"USB_CC1": -1.25, "USB_CC2": 1.75}
CC_RESISTOR = {"USB_CC1": "R1", "USB_CC2": "R2"}

USB_PAIR_KEEPOUT_HALF_WIDTH_MM = 2.4

#: The bridge faces its data pins south so the pair reaches them in a
#: straight line; its transmit and receive pins then face west, its reset
#: and suspend pins east, and the seven pins this board does not use north,
#: where nothing has to reach them.
BRIDGE_MM = (9.75, 24.6)
BRIDGE_THERMAL_HALF_MM = 1.45
BRIDGE_THERMAL_ESCAPE_MM = 2.30
#: The thermal land's escape is drawn at the board's minimum track width and
#: nothing wider. The corner it leaves through is bounded by the inner
#: corners of the two nearest lands, which stand 0.46 mm apart whatever the
#: thermal land's own size: only a track this narrow passes between them at
#: the board's clearance.
BRIDGE_THERMAL_ESCAPE_WIDTH_MM = 0.15
#: The ring between the thermal land and the perimeter lands is half a
#: millimetre wide. A conductor and its clearance fit in it only at the
#: board's floor, and a search that finds that out routes a signal through
#: the middle of a package - which is what the first run did. The four
#: sides of that ring are closed to tracks and vias; the corners are left
#: open because the thermal land's own escape leaves through two of them.
BRIDGE_RING_INNER_MM = 1.45
BRIDGE_RING_OUTER_MM = 1.95
#: How far along each side the closure reaches. Short of the corner, so the
#: thermal land's own two escapes leave through copper nothing forbids.
BRIDGE_RING_SPAN_MM = 1.20

#: The bridge's own escapes. Its lands are half a millimetre apart, and a
#: quarter-millimetre conductor between two of them has a quarter of a
#: millimetre either side - legal on this board, and less than the margin
#: the router is given to work to, so the router reports the pin boxed in
#: and gives up. There is no search freedom in a fine-pitch escape anyway:
#: it leaves its land the one way it can, straight out, and fans to a pitch
#: a search can work at. Which pins need one is a fact about the package and
#: about which of its neighbours this board leaves unconnected.
BRIDGE_ESCAPE_PINS = ("VBUS", "RSTB", "SUSPENDB", "CTS", "RTS", "RXD", "TXD")
BRIDGE_ESCAPE_RADIAL_MM = 3.30
BRIDGE_ESCAPE_FANOUT_MM = 4.20
BRIDGE_ESCAPE_SPREAD = 1.6
HEADER_PIN1_MM = (3.65, 39.5)
HEADER_PITCH_MM = 2.54

#: Where each probe's name is printed, chosen per probe because the room
#: beside a one-millimetre pad is whatever its neighbours have left.
PROBE_LABEL_OFFSET_MM = {"TP1": (2.4, 0.0), "TP2": (-3.0, 0.0),
                         "TP3": (0.0, 1.9)}

PLACEMENT = {
    "J1": RECEPTACLE_MM + (0.0,),
    "D1": SUPPRESSOR_MM + (90.0,),
    "U1": BRIDGE_MM + (90.0,),
    "J2": HEADER_PIN1_MM + (90.0,),

    # the receptacle's own network: the two sink terminations beside the
    # lands they belong to, the sense divider up the east side, and the
    # bypass and its probe up the west
    "R1": (6.40, 10.80, 180.0),
    "R2": (13.60, 10.80, 0.0),
    "R4": (16.80, 11.00, 90.0),
    "R5": (16.80, 14.40, 90.0),
    "C1": (3.20, 12.80, 0.0),
    # the hundred nanofarads that belongs to the suppressor's own rail pin
    # rather than to the regulator's input, so it sits where that pin's
    # conductor comes out rather than beside the bulk on the far side
    "C2": (13.20, 20.00, 90.0),
    "TP1": (2.20, 16.40, 0.0),

    # the bridge's own bypass: a hundred nanofarads at each supply pin and
    # the bulk beyond it, all east of the pair's corridor
    "C8": (14.00, 17.00, 0.0),
    "C7": (17.40, 17.00, 0.0),
    "C6": (15.80, 20.60, 0.0),
    "C5": (16.60, 22.60, 0.0),

    # the regulator and the rail it makes, up the west side
    "U2": (3.60, 20.40, 180.0),
    "C3": (3.20, 25.20, 0.0),
    "C4": (3.20, 27.20, 0.0),

    # rail bulk north of the bridge, which is what a target plugged in live
    # shares charge with
    "C9": (4.50, 29.30, 0.0),
    "C10": (8.00, 29.30, 0.0),
    "C11": (4.50, 32.00, 0.0),
    "R3": (8.00, 32.00, 0.0),

    # the target-supply switch, its driver and the two resistors that hold
    # it off, up the east side
    "Q1": (16.00, 26.00, 0.0),
    "Q2": (16.00, 29.80, 0.0),
    "Q3": (11.80, 29.70, 0.0),
    "R6": (19.00, 29.80, 90.0),
    "R7": (19.00, 26.00, 90.0),

    "TP2": (18.60, 19.00, 0.0),
    "TP3": (2.20, 34.60, 0.0),

    # the four series elements, each below the header pin it feeds
    "R11": (6.19, 35.50, 90.0),
    "R8": (11.27, 35.50, 90.0),
    "R9": (13.81, 35.50, 90.0),
    "R10": (16.35, 35.50, 90.0),
}


#: Parts a placement search may not move, and why. The connectors and the
#: probes are the board's mechanical and service contract; the suppressor's
#: position is the requirement that it sits between the receptacle and
#: everything downstream; the bridge anchors the pair.
LOCKED_REFERENCES = tuple(sorted(
    [reference for reference in netlist.PARTS
     if reference[0] in ("J",) and reference[1:].isdigit()]
    + [reference for reference in netlist.PARTS
       if reference.startswith("TP")]
    + ["D1", "U1"]))

#: The probe pads on the pair are points on it, not spurs off it: the
#: conductor enters one side and leaves the other through the pad's own
#: anchor, so nothing hangs and nothing is left touching a pad only at its
#: edge. The pair spreads to reach them, because two pads a millimetre
#: across cannot stand on two conductors half a millimetre apart.


def _pair_probe_pose(net):
    sign = -1.0 if net == "USB_DP" else 1.0
    return (PAIR_CENTRE_X_MM + sign * PROBE_DX_MM, PROBE_Y_MM, 0.0)


def seed_placement():
    placed = dict(PLACEMENT)
    placed["TP4"] = _pair_probe_pose("USB_DP")
    placed["TP5"] = _pair_probe_pose("USB_DM")
    return placed


def accepted_placement():
    """The placement a search accepted, if one has been recorded."""
    if not os.path.isfile(PLACEMENT_PATH):
        return {}
    with open(PLACEMENT_PATH, encoding="utf-8") as handle:
        document = json.load(handle)
    return {reference: tuple(pose)
            for reference, pose in document["placement"].items()
            if reference not in LOCKED_REFERENCES}


def fixed_placements():
    placed = seed_placement()
    for reference, pose in accepted_placement().items():
        if reference not in placed:
            raise KeyError("accepted placement names an unknown part: "
                           + reference)
        placed[reference] = pose
    missing = sorted(reference for reference, part in netlist.PARTS.items()
                     if part["footprint"] and reference not in placed)
    if missing:
        raise KeyError("no placement for " + ", ".join(missing))
    return placed


def to_board(x_mm, y_mm):
    return (ORIGIN_MM[0] + x_mm, ORIGIN_MM[1] - y_mm)


def _point(x_mm, y_mm):
    bx, by = to_board(x_mm, y_mm)
    return pcbnew.VECTOR2I(pcbnew.FromMM(bx), pcbnew.FromMM(by))


def _footprint_dir(footprint):
    library, _, name = footprint.partition(":")
    for base in FOOTPRINT_SEARCH_PATHS:
        candidate = os.path.join(base, library + ".pretty")
        if os.path.isfile(os.path.join(candidate, name + ".kicad_mod")):
            return candidate, name
    raise FileNotFoundError(footprint)


_PIN_NAMES = {}


def _pin_name(lib_id, number):
    if lib_id not in _PIN_NAMES:
        library = ksym.Library(netlist.SYMBOL_LIBRARY_PATHS)
        _PIN_NAMES[lib_id] = {
            key: pins[0].name for key, pins in library.pins(lib_id).items()}
    return _PIN_NAMES[lib_id].get(number, "")


def _floating_net(board, reference, number):
    lib_id = netlist.PARTS[reference]["lib_id"]
    name = "unconnected-(%s-%s-Pad%s)" % (
        reference, _pin_name(lib_id, number).replace("/", "{slash}"), number)
    existing = board.GetNetInfo().GetNetItem(name)
    if existing is not None and existing.GetNetCode() != 0:
        return existing
    net = pcbnew.NETINFO_ITEM(board, name)
    _NET_RECORDS.append(net)
    board.Add(net)
    return net


def _load(board, reference, part, x, y, rotation, pin_net):
    library_dir, name = _footprint_dir(part["footprint"])
    footprint = pcbnew.FootprintLoad(library_dir, name)
    if footprint is None:
        raise RuntimeError("could not load " + part["footprint"])
    library = part["footprint"].partition(":")[0]
    footprint.SetFPID(pcbnew.LIB_ID(library, name))
    footprint.SetPosition(_point(x, y))
    footprint.SetOrientationDegrees(rotation)
    footprint.SetReference(reference)
    footprint.SetValue(part["value"])
    footprint.Reference().SetLayer(pcbnew.F_Fab)
    footprint.Value().SetLayer(pcbnew.F_Fab)
    for key, value in (("MPN", part["mpn"]), ("LCSC", part["lcsc"]),
                       ("Manufacturer", part["manufacturer"])):
        if not value:
            continue
        footprint.SetField(key, value)
        for field in footprint.GetFields():
            if field.GetName() == key:
                field.SetLayer(pcbnew.F_Fab)
                field.SetVisible(False)
    if not part["in_bom"]:
        footprint.SetExcludedFromBOM(True)
    if reference in LOCKED_REFERENCES:
        footprint.SetLocked(True)
    for pad in footprint.Pads():
        number = pad.GetNumber()
        if not number:
            continue
        net_name = pin_net.get("%s.%s" % (reference, number))
        if net_name:
            pad.SetNet(_net(board, net_name))
        else:
            pad.SetNet(_floating_net(board, reference, number))
    board.Add(_own(footprint))
    return footprint


#: Every net record this module creates, kept for as long as the process
#: runs. Adding a net to a board is supposed to hand the board its
#: ownership, but the binding leaves the Python wrapper owning it too: drop
#: the last reference and the record is freed while the board still points
#: at it, and the next thing to be written into that memory becomes the net
#: a via belongs to. One stitch between the two ground pours was saved on
#: the supply that way.
_NET_RECORDS = []

#: And every other item this module hands to a board, for the same reason.
#: `BOARD::Add` is supposed to take ownership; the binding leaves the Python
#: wrapper owning it as well, so the moment the last reference goes the item
#: is freed under the board. Whatever is written into that memory next
#: becomes what the board writes out - which is how one stitch between the
#: two ground pours came back saved on the supply net.
_ITEMS = []


def _own(item):
    _ITEMS.append(item)
    return item


def _create_nets(board):
    _NET_CACHE.clear()
    for name in sorted(netlist.NETS):
        record = pcbnew.NETINFO_ITEM(board, name)
        _NET_RECORDS.append(record)
        board.Add(record)


#: One wrapper per net, looked up once and then reused. Every lookup
#: returns a fresh Python object over a record the board owns, and the
#: binding lets those objects own it too: a lookup whose wrapper is
#: collected takes the board's record with it, and the next record created
#: lands in the same memory. That is how one stitch between the two ground
#: pours came back written on the supply net.
_NET_CACHE = {}


def _net(board, name):
    """The board's own record for a net name, looked up once."""
    if name not in _NET_CACHE:
        net = board.GetNetInfo().GetNetItem(name)
        if net is None or net.GetNetCode() == 0:
            raise KeyError("the board carries no net named " + name)
        _NET_CACHE[name] = net
    return _NET_CACHE[name]


def _design_settings(board):
    board.SetCopperLayerCount(2)
    settings = board.GetDesignSettings()
    settings.m_TrackMinWidth = pcbnew.FromMM(0.15)
    settings.m_ViasMinSize = pcbnew.FromMM(0.45)
    settings.m_MinThroughDrill = pcbnew.FromMM(0.25)
    settings.m_CopperEdgeClearance = pcbnew.FromMM(EDGE_CLEARANCE_MM)
    settings.m_HoleClearance = pcbnew.FromMM(0.25)
    settings.m_HoleToHoleMin = pcbnew.FromMM(0.25)
    settings.m_ViasMinAnnularWidth = pcbnew.FromMM(0.1)
    settings.m_MinClearance = pcbnew.FromMM(CLEARANCE_MM)
    default_class = settings.m_NetSettings.GetDefaultNetclass()
    default_class.SetClearance(pcbnew.FromMM(CLEARANCE_MM))
    default_class.SetTrackWidth(pcbnew.FromMM(TRACK_WIDTH_MM))
    default_class.SetViaDiameter(pcbnew.FromMM(VIA_DIAMETER_MM))
    default_class.SetViaDrill(pcbnew.FromMM(VIA_DRILL_MM))


def _add_outline(board):
    corners = [(0.0, 0.0), (BOARD_W_MM, 0.0), (BOARD_W_MM, BOARD_H_MM),
               (0.0, BOARD_H_MM)]
    closed = corners + [corners[0]]
    for start, end in zip(closed, closed[1:]):
        shape = pcbnew.PCB_SHAPE(board)
        shape.SetShape(pcbnew.SHAPE_T_SEGMENT)
        shape.SetStart(_point(*start))
        shape.SetEnd(_point(*end))
        shape.SetLayer(pcbnew.Edge_Cuts)
        shape.SetWidth(pcbnew.FromMM(EDGE_WIDTH_MM))
        board.Add(_own(shape))


def _rectangle_zone(board, corners, layers):
    zone = pcbnew.ZONE(board)
    layer_set = pcbnew.LSET()
    for layer in layers:
        layer_set.addLayer(layer)
    zone.SetLayerSet(layer_set)
    outline = zone.Outline()
    outline.NewOutline()
    for x, y in corners:
        bx, by = to_board(x, y)
        outline.Append(pcbnew.FromMM(bx), pcbnew.FromMM(by))
    return zone


def _pour(board, net, corners, layers, priority=0):
    zone = _rectangle_zone(board, corners, layers)
    zone.SetNet(net)
    zone.SetAssignedPriority(priority)
    zone.SetLocalClearance(pcbnew.FromMM(CLEARANCE_MM))
    zone.SetMinThickness(pcbnew.FromMM(ZONE_MIN_WIDTH_MM))
    zone.SetPadConnection(pcbnew.ZONE_CONNECTION_FULL)
    zone.SetThermalReliefGap(pcbnew.FromMM(0.3))
    zone.SetThermalReliefSpokeWidth(pcbnew.FromMM(0.4))
    board.Add(_own(zone))
    return zone


def pair_corridor_mm():
    """The band the front pour is kept out of, and why it is that wide.

    The pair's impedance and delay are reported from a microstrip model,
    whose reference is the plane below. Front-layer copper running alongside
    at less than the dielectric thickness would couple to the conductors
    more strongly than that plane does, and the reported numbers would then
    describe a structure this board does not have. The corridor is therefore
    wider than the dielectric is thick.
    """
    half = USB_PAIR_KEEPOUT_HALF_WIDTH_MM
    return (PAIR_CENTRE_X_MM - half, max(LINK_Y_MM.values()) + 0.6,
            PAIR_CENTRE_X_MM + half, CONVERGE_Y_MM + 0.2)


def _rule_area(board, corners, layers, fills=False, tracks=False,
               vias=False):
    zone = _rectangle_zone(board, corners, layers)
    zone.SetIsRuleArea(True)
    zone.SetDoNotAllowZoneFills(fills)
    zone.SetDoNotAllowTracks(tracks)
    zone.SetDoNotAllowVias(vias)
    zone.SetDoNotAllowPads(False)
    zone.SetDoNotAllowFootprints(False)
    board.Add(_own(zone))
    return zone


def bridge_ring_areas_mm():
    """The four sides of the bridge's land ring, as rectangles."""
    x, y, _rotation = fixed_placements()["U1"]
    inner, outer = BRIDGE_RING_INNER_MM, BRIDGE_RING_OUTER_MM
    span = BRIDGE_RING_SPAN_MM
    return [
        (x - span, y + inner, x + span, y + outer),
        (x - span, y - outer, x + span, y - inner),
        (x - outer, y - span, x - inner, y + span),
        (x + inner, y - span, x + outer, y + span),
    ]


def unreferenced_budgets_mm():
    """How much of each conductor runs with no reference, and from what.

    Not a tolerance and not a measurement: the sum of the interruptions the
    design source itself puts in the way, priced from this board's own
    conductor width, via diameter, clearance and minimum pour width. A
    routed board that measures more than this has something in it that the
    design source did not put there.

    On the front layer, over the plane, each conductor meets:

    * the other line's orientation link, which the receptacle's land order
      forces onto the back layer and across this conductor;
    * the suppressor's rail conductor, which its package puts between the
      two protected paths;
    * its own layer change, whose barrel and clearance take the plane out
      from under the very copper that lands on it;

    and, beside each of those, one strip of plane that can come out
    narrower than the fabricator will etch and so is not poured at all.

    On the back layer, the orientation link runs under the receptacle's
    launch, where the four fan-out conductors and their clearances leave no
    front area wide enough to pour. The whole link, plus the clearance the
    front copper is held off by at each end, is unreferenced.
    """
    cuts = ((TRACK_WIDTH_MM + 2 * CLEARANCE_MM),      # the other line's link
            (TRACK_WIDTH_MM + 2 * CLEARANCE_MM),      # the suppressor's rail
            (VIA_DIAMETER_MM + 2 * CLEARANCE_MM))     # the conductor's own via
    front = sum(cut + ZONE_MIN_WIDTH_MM for cut in cuts)
    back = max(abs(FANOUT_X_MM[netlist.USB_C_PAIR_TERMINALS[net]]
                   - FANOUT_X_MM[netlist.USB_C_FLIPPED_TERMINALS[net]])
               for net in netlist.USB_C_PAIR_TERMINALS) + 2 * CLEARANCE_MM
    return front, back
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

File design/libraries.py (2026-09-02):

"""What KiCad's own libraries do not carry, generated from the drawings.

Almost everything this board uses - the suppressor, the receptacle, the
transistors, the passives - is a stock KiCad symbol on a stock KiCad
footprint, so the board owns no copy of it. Two things are not.

The regulator's symbol, because KiCad ships no XC6206; it is generated from
the pin assignment table in the Torex datasheet.

The bridge's land pattern, because the stock QFN-28 patterns put no paste on
the thermal land at all - the part would reflow on its perimeter pads with
its centre pad dry - and because their thermal land is wide enough to seal
the perimeter ring, leaving no way to reach it with copper. The pattern here
is generated from the bridge datasheet's own land-pattern table and its
notes, and its thermal land is sized to leave a diagonal corridor at each
corner: the ground connection is then made with copper rather than with a
via standing in a pad that receives solder.
"""
from __future__ import annotations

import os
import sys

REPO_ROOT = os.path.dirname(os.path.dirname(os.path.abspath(__file__)))
LIBRARY_NAME = "UsbCUartDebugger"
SYMBOL_LIB_PATH = os.path.join(REPO_ROOT, "library",
                               LIBRARY_NAME + ".kicad_sym")
FOOTPRINT_DIR = os.path.join(REPO_ROOT, "library", LIBRARY_NAME + ".pretty")
SYM_LIB_TABLE = os.path.join(REPO_ROOT, "sym-lib-table")
FP_LIB_TABLE = os.path.join(REPO_ROOT, "fp-lib-table")

SYMBOL_LIB_VERSION = "20251024"
FOOTPRINT_VERSION = "20260206"
GENERATOR = "usb-c-uart-debugger-design-source"

# CP2102N data sheet Rev 1.5, table 6.2 "QFN28 PCB Land Pattern Dimensions"
# and its notes. Every dimension in that table is stated as a maximum, so
# each value below is at or under the one the table gives.
#
#   E  = 0.50        land pitch
#   X1 = 0.30 max    perimeter land width      -> 0.25
#   Y1 = 0.95 max    perimeter land length     -> 0.90
#   C1 = C2 = 4.80   land centre span          -> centres at +/- 2.40
#   X2 = Y2 = 3.35   thermal land              -> 2.90
#
# The thermal land is well under its maximum on purpose. At 3.35 it would
# leave 0.275 mm between itself and the perimeter ring, which no conductor
# and no pour can pass; at 2.90 the diagonal corridor at each corner is wide
# enough for a track at the board's own clearance, so the land is reached
# with copper instead of with a via in a pad that takes paste.
#
# Note 7 gives the stencil for the centre pad as a 2 x 2 array of 1.2 mm
# square openings on a 1.5 mm pitch, and note 6 gives 1:1 apertures for the
# perimeter lands; both are followed. Note 3 asks for a 60 um solder-mask
# clearance all round each land, which is NOT followed: at this pitch it
# would leave a 0.13 mm mask dam between neighbouring lands, and no mask-dam
# or mask-expansion capability is among this board's frozen fabricator
# evidence, so the board states no expansion of its own and leaves it to the
# process. That deviation is recorded rather than quietly taken.
BRIDGE_FOOTPRINT_NAME = "QFN-28-1EP_5x5mm_P0.5mm_CP2102N"
BRIDGE_PITCH_MM = 0.50
BRIDGE_PAD_WIDTH_MM = 0.25
BRIDGE_PAD_LENGTH_MM = 0.90
BRIDGE_PAD_CENTRE_MM = 2.40
BRIDGE_PADS_PER_SIDE = 7
BRIDGE_THERMAL_LAND_MM = 2.90
BRIDGE_THERMAL_PASTE_MM = 1.20
BRIDGE_THERMAL_PASTE_PITCH_MM = 1.50
BRIDGE_BODY_MM = 5.00
BRIDGE_COURTYARD_MARGIN_MM = 0.25
BRIDGE_DATASHEET = ("https://www.silabs.com/documents/public/data-sheets/"
                    "cp2102n-datasheet.pdf")

#: Torex XC6206 series, PIN ASSIGNMENT table: in SOT-89 the pins are VSS,
#: VIN, VOUT on 1, 2, 3. The regulator is the only source on the logic rail,
#: so its output is declared power_out and the rail needs no separate flag.
LDO_SYMBOL_NAME = "XC6206Pxx2PR"
LDO_PINS = (("1", "VSS", "power_in", "bottom"),
            ("2", "VIN", "power_in", "left"),
            ("3", "VOUT", "power_out", "right"))
LDO_DATASHEET = "https://product.torexsemi.com/system/files/series/xc6206.pdf"
LDO_FOOTPRINT = "Package_TO_SOT_SMD:SOT-89-3"
LDO_FOOTPRINT_FILTER = "SOT?89*"


def _effects():
    return ("\n\t\t\t\t(effects\n\t\t\t\t\t(font\n"
            "\t\t\t\t\t\t(size 1.27 1.27)\n\t\t\t\t\t)\n\t\t\t\t)")


def _symbol_property(key, value, index, hide):
    hidden = "\n\t\t\t(hide yes)" if hide else ""
    return ('\t\t(property "%s" "%s"\n\t\t\t(at 0 %.2f 0)%s\n'
            '\t\t\t(effects\n\t\t\t\t(font\n\t\t\t\t\t(size 1.27 1.27)\n'
            '\t\t\t\t)\n\t\t\t)\n\t\t)'
            % (key, value, 17.78 - 2.54 * index, hidden))


def _pin_text(kind, x, y, angle, name, number):
    return ('\t\t\t(pin %s line\n\t\t\t\t(at %.2f %.2f %d)\n'
            '\t\t\t\t(length 2.54)\n'
            '\t\t\t\t(name "%s"%s\n\t\t\t\t)\n'
            '\t\t\t\t(number "%s"%s\n\t\t\t\t)\n\t\t\t)'
            % (kind, x, y, angle, name, _effects(), number, _effects()))


def _rectangle(half_x, half_y):
    return ['\t\t\t(rectangle',
            '\t\t\t\t(start %.2f %.2f)' % (-half_x, half_y),
            '\t\t\t\t(end %.2f %.2f)' % (half_x, -half_y),
            '\t\t\t\t(stroke\n\t\t\t\t\t(width 0.254)\n'
            '\t\t\t\t\t(type default)\n\t\t\t\t)',
            '\t\t\t\t(fill\n\t\t\t\t\t(type background)\n\t\t\t\t)',
            '\t\t\t)']


def _placed_pin(entry, placed_pins, half_x, half_y):
    number, pin_name, kind, side = entry
    same_side = [item for item in placed_pins if item[3] == side]
    index = same_side.index(entry)
    span = 2.54 * (len(same_side) - 1) / 2.0
    if side == "left":
        return _pin_text(kind, -half_x - 2.54, span - 2.54 * index, 0,
                         pin_name, number)
    if side == "right":
        return _pin_text(kind, half_x + 2.54, span - 2.54 * index, 180,
                         pin_name, number)
    if side == "bottom":
        return _pin_text(kind, 2.54 * index - span, -half_y - 2.54, 90,
                         pin_name, number)
    return _pin_text(kind, 2.54 * index - span, half_y + 2.54, 270,
                     pin_name, number)


def ldo_symbol_text():
    placed = list(LDO_PINS)
    half_x, half_y = 5.08, 3.81
    lines = ['\t(symbol "%s"' % LDO_SYMBOL_NAME,
             '\t\t(pin_names\n\t\t\t(offset 1.016)\n\t\t)',
             '\t\t(exclude_from_sim no)',
             '\t\t(in_bom yes)',
             '\t\t(on_board yes)',
             _symbol_property("Reference", "U", 0, False),
             _symbol_property("Value", LDO_SYMBOL_NAME, 1, False),
             _symbol_property("Footprint", LDO_FOOTPRINT, 2, True),
             _symbol_property("Datasheet", LDO_DATASHEET, 3, True),
             _symbol_property("ki_fp_filters", LDO_FOOTPRINT_FILTER, 4, True),
             '\t\t(symbol "%s_0_1"' % LDO_SYMBOL_NAME]
    lines.extend(_rectangle(half_x, half_y))
    lines.append('\t\t)')
    lines.append('\t\t(symbol "%s_1_1"' % LDO_SYMBOL_NAME)
    for entry in placed:
        lines.append(_placed_pin(entry, placed, half_x, half_y))
    lines.append('\t\t)')
    lines.append('\t)')
    return "\n".join(lines)
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

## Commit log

2026-08-30 Seed benchmark board 05/32 from its supplied brief
    PCBA_USB_C_UART_Debugger is one of thirty-two boards in the PCBA_AutoDesignAndTest
    benchmark. This commit establishes the repository and nothing else:
    the board is not designed, and its absence is the intended state.
    BRIEF.md is the supplied brief, preserved byte for byte and
    authoritative. board/requirements.json splits it into fixed_requirements
    -- each carrying the verbatim brief text that substantiates it, bound to
    the SHA-256 of the brief's bytes -- and open_decisions, which are the
    design agent's to make and to record as choices. Promoting a decision
    into a requirement is the failure the split exists to prevent.
    docs/architecture.md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
2026-08-30 Stop the scaffold claiming a check it does not perform
    An external review of the pushed benchmark found this repository asserting
    three things about itself that were not true as shipped.
    board/manifest.template.json said running the validator against it "will
    fail on the missing source". It does not: `run.py validate
    board/manifest.template.json` exits 0 and prints ACCEPTED, with all 36 gates
    NOT_APPLICABLE and no gate reading sources.pcb, so the absent board file is
    never noticed. The template now says exactly that, under verdict_warning,
    and docs/status.md and CLAUDE.md carry the same warning where a reader and
    an agent will actually meet it. The toolkit is behaving as designed - a gate
    w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
2026-08-30 Remove the claim-audit skill, and the instructions that called it
    Requested. .claude/skills/claim-audit/ is deleted, and with it every
    reference: CLAUDE.md's publishing discipline no longer names it, and the
    README layout table no longer advertises it.
    accountability-review kept calling it at step 3, which would have left the
    surviving skill invoking one that is not in the clone - the same
    dangling-instruction defect that put these skills in the repository in the
    first place. That step now states the claim-binding work directly: scan the
    drafts for claim-bearing words, and bind each to an artifact recomputed on
    the spot rather than to the process that produced it. The discipline is
    unchange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
2026-08-30 Finish removing claim-audit: the last prose reference to it
    accountability-review still explained itself with "that is why the claim
    audit runs first". Nothing runs first any more - the claim binding is step 3
    of this skill, and it runs before the review package is assembled, not
    before the review. The sentence now says that.
    Removing a skill is not done when its file is gone. It is done when nothing
    left in the repository tells a reader to go and find it.
2026-08-30 Review against this repository's own invariants, not another board's
    /accountability-review assembled its review package with a hardcoded list
    of "standing invariants", and that list belonged to a different project and
    an abandoned workflow: "never modify the authoritative Board A PCB" names a
    board that does not exist here, and "never touch main" and "no PRs"
    describe a process the opposite of this one -- every repository in this
    benchmark is developed on main and pushed directly.
    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
2026-08-30 Delete generated prose; keep the seed brief and machine-consumed config
    The seed pack already contained the human-authored specification for this
    board. Everything this repository added on top was a reinterpretation of it:
    a README and CLAUDE.md narrating the brief, an architecture worksheet of
    English questions, status and sources documents, a prose requirements
    document, and requirements.json - which restated the brief as English
    requirement strings and copied 20-odd verbatim quotations back out of a file
    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
2026-09-02 Design the USB-C UART debugger schematic and its evidence
    The bridge is a CP2102N with its internal regulator bypassed. That is the
    first real finding: the regulator's input is specified to 5.25 V and the
    VBUS-max ECN lets a compliant source present 5.50 V, so a bus-powered board
    using it would run it outside its recommended range. An external XC6206 in
    SOT-89 takes the whole range instead, and brings a stated dropout at 100 mA,
    a stated short-circuit current and 3 uA of quiescent draw with it.
    The target's supply pin is switched by two P-channel transistors back to
    back, driven from the bridge's own SUSPEND output. That one arrangement
    answers three separate requirements: the suspend ceili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
    [usb_c_uart_debugger.kicad_sch]
2026-09-02 Simulate the four questions the schematic can answer
    The hot-plug scenario is the one that mattered. The requirement report
    answers it by sharing charge between two capacitances instantaneously; the
    network agrees to within thirty microvolts, which is the useful result -
    the switch's resistance and the finite event change nothing, so the
    arithmetic was not hiding anything, and the rail's floor really is set by
    how much capacitance sits on it against how much a target brings.
    That is why the rail carries six bulk capacitors rather than three. Working
    the sharing backwards from the bridge's own supply-monitor threshold is what
    fixes the budget a target may present at 4.7 uF, and the capacitan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
    [rules.py, simulation.py]
2026-09-02 Advance the debugger to a routed, fabricable board
    Place, generate and route the board, declare the pair as electrical paths
    the toolkit measures on the copper, and install the fabrication outputs the
    validated state produces.
    The receptacle's four data terminals alternate along its land row, so the
    two links that join each line's pair of terminals are non-planar: one of
    them has to cross the other conductor on the back layer. That single fact
    sets the launch geometry, the one layer change per conductor, and what the
    plane under the pair is allowed to be missing. The design source names the
    interruptions item by item and the layout prices them from the board's own
    track width, via diameter,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
    [bom.csv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]
2026-09-03 Record what this board needed from the toolkit and did not have
2026-09-03 Rebind the release to the phase 0 toolkit
    The toolkit now validates every manifest against its published schema
    and refuses vocabulary it does not implement, so the board-local gate
    list moves under the x_ extension prefix; gate-class selection
    (--only=design) supersedes it. Regenerated and revalidated against
    toolkit f4d3904: 27 gates pass, 9 report NOT_APPLICABLE, and
    the fabrication record now carries the source-closure member map, so
    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
    [usb_c_uart_debugger-B_Cu.gbr, usb_c_uart_debugger-B_Mask.gbr, usb_c_uart_debugger-B_Silkscreen.gbr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]
2026-09-03 Retire the hand-written routing acceptance list
    The toolkit's design gate class replaces it: candidate acceptance now
    selects --only=design, expanded by the toolkit, so the set cannot rot
    as gates are added. The list leaves the manifest and the generator that writes it, and the
    release is regenerated under toolkit b441685, which also closes the
    review findings on the phase 0 seams: 27 gates pass, 9 report
    NOT_APPLICABLE.
    [usb_c_uart_debugger-B_Cu.gbr, usb_c_uart_debugger-B_Mask.gbr, usb_c_uart_debugger-B_Silkscreen.gbr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]
2026-09-03 Close the adversarial findings that reached this board
    The unread keys the manifest carried are gone: tolerance_seconds is
    deleted, contact_semantics becomes the note annotation it always was,
    and the schema now refuses both by name. The routing acceptance
    selection regains ROUTE.PROVENANCE - the loop writes the record before
    judging, so record-board agreement is judged per candidate as it was
    under the hand-written list. Regenerated and revalidated under
    toolkit a0f53eb: 27 gates pass, 9 report NOT_APPLICABLE.
    [usb_c_uart_debugger-B_Cu.gbr, usb_c_uart_debugger-B_Mask.gbr, usb_c_uart_debugger-B_Silkscreen.gbr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]
2026-09-03 Rebind the release to toolkit 0c051f2
    The toolkit keeps its CLI alive with no display and closes the third
    review round's findings; nothing in this board's own sources moved.
    27 gates pass, 9 report NOT_APPLICABLE.
    [usb_c_uart_debugger-B_Cu.gbr, usb_c_uart_debugger-B_Mask.gbr, usb_c_uart_debugger-B_Silkscreen.gbr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]
2026-09-03 Rebind the release to toolkit 7f51066
    The panel-fix round widened the source closure to every staged design
    input and hardened the verdict binding, so the fabrication outputs and
    the recorded verdict are regenerated under the new toolkit. The
    transient .pcbqa-hold-* lock file is ignored.
    [usb_c_uart_debugger-B_Cu.gbr, usb_c_uart_debugger-B_Mask.gbr, usb_c_uart_debugger-B_Silkscreen.gbr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]
